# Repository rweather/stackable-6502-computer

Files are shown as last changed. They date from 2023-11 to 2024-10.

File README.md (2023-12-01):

Stackable 6502 Computer
=======================

This repository contains schematics, PCB layouts, and other information
for a "stackable" design for a 6502-based computer based on
[Ben Eater's Breadboard 6502 Computer](https://eater.net/6502) with
options to expand with daughter boards (or "shields" in the Arduino sense).

The CPU, memory, VIA, and address decoding are on the base board with pin
headers to connect to other boards:

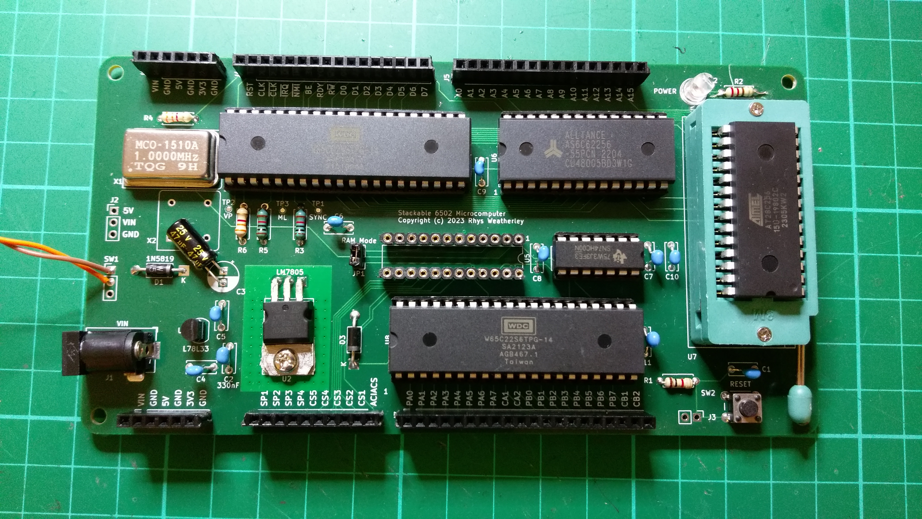
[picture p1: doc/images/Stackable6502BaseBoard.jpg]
Stackable 6502 Computer Base Board


Here is the Stackable 6502 Computer with the I/O board fitted:

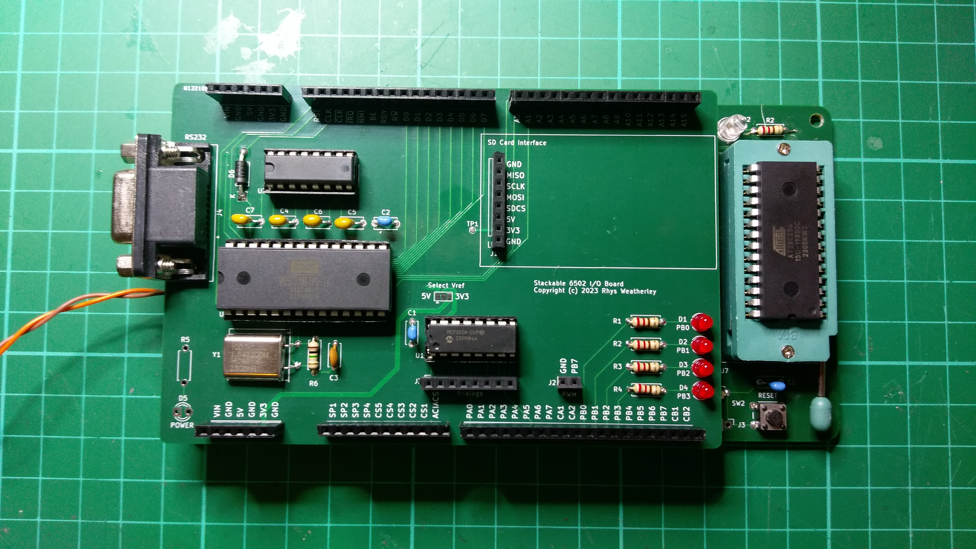
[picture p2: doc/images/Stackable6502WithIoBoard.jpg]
Stackable 6502 Computer with I/O Board


Other boards are possible in the future; see **Future Expansion Ideas** below.

Repository Layout
-----------------

* `kicad` - Schematics and PCB layouts in [KiCad format](https://www.kicad.org/).
* `kicad/BaseBoard` - Base board schematic and layout (4-layer).
* `kicad/IoBoard` - I/O board schematic and layout (2-layer).
* `kicad/Library` - Library of common schematic symbols and footprints.
* `schematics` - PDF versions of the schematics.
* `gerber` - Gerber files for all of the boards.
* `roms` - ROM images for test programs.
* `src` - Source code for test programs.

Schematics and Parts
--------------------

PDF versions of the schematics are available for the
[Base Board](schematics/BaseBoard.pdf) and [I/O Board](schematics/IoBoard.pdf)
in the `schematics` subdirectory.  The `gerber` directory contains the
Gerber files if you want to get your own PCB's made.

I used [PCBway](https://www.pcbway.com/) for my PCB's.  The PCB's for
the base board and I/O board are 4-layer boards.  You can order your
own PCB's from PCBway here:

* [Base Board](https://www.pcbway.com/project/shareproject/W132188ASZ13_Stackable_6502_BaseBoard_01ef6257.html)
* [I/O Board](https://www.pcbway.com/project/shareproject/W132188ASZ14_Stackable_6502_IoBoard_ac81ba96.html)

The parts list for this project can be found in the file
[Parts.md](doc/Parts.md) in the `doc` subdirectory.  There are some
alternatives on how you can build it, so some parts are optional:

* The 1MHz crystal oscillator can use either the 14-pin DIP style package (X1)
or the 8-pin DIP style package (X2) version.  Fit only one of the oscillators.
* Address decoding can use either a simple 74LS00 NAND gate, or a
ATF22V10C-7PX Programmable Logic Device (PLD).  It is easiest to start with
the NAND gate, but the PLD provides a lot of flexibility in memory layout.
* Optional 3.3V power supply using a L78L33 3.3V voltage regulator.
This will be handy if you plan to interface to 3.3V equipment using
level conversion.
* MCP3208 12-bit SPI ADC on the I/O board for reading analog inputs.

I suggest studying the schematics and the build instructions before
deciding which options you need.

Base Board
----------

The 156mm x 82mm base board was based on the design for
[Ben Eater's Breadboard 6502 Computer](https://eater.net/6502) with some
modifications to help with expandability:

* W65C02S or pin-compatible microprocessor.
* 62256 32K x 8 static RAM.
* 28C256 32K x 8 EEPROM, mounted in a 28-pin ZIF socket at the end of the
  base board to give clearance between the socket and daughter boards.
  A regular 28-pin socket can be used instead of the ZIF if you prefer.
* 6522 Versatile Interface Adapter (VIA).
* Address decoding logic using either a 74LS00 quad NAND gate as in Ben Eater's
  original design, or a ATF22V10C-7PX programmable logic device (PLD).
* 5V and 3.3V power supplies based on a 9-12V DC input.
* Pin headers to expose power, bus lines, and control lines to the
  attached daughter boards.
* 4-layer PCB with ground and 5V on the two inner layers.

The pin headers are aligned on a strict 2.54mm (0.1 inch) grid to allow
standard 120mm x 80mm stripboard or protoboard to be used when creating
daughter board "shields".

If you want to lay out your own shield PCB, then you can use the
`Stackable6502Shield` symbol and footprint from `kicad/Library`
as a starting point.

See [Build-Base-Board.md](doc/Build-Base-Board.md) in the `doc`
subdirectory for instructions on building the base board.

I/O Board
---------

The 125 x 82mm I/O board provides the following features:

* RS-232 serial interface using the 6551 ACIA, with RTS handshaking.
* SPI bus interface, connected to the 6522 VIA on the base board.
* SD card interface, connected to the SPI bus interface.
* 8 analog inputs using the MCP3208 12-bit SPI ADC chip.
* "PWM" header for square wave output on PB7 of the 6522 VIA.
  A piezo-buzzer can be connected to the header for making simple sounds.
* Provision for 3mm LED's on PB0..PB3 for indication.

As can be seen, the I/O board is very featureful.  Not all features need
to be fitted at once.  You can customise it for your requirements.

See [Build-Io-Board.md](doc/Build-Io-Board.md) in the `doc`
subdirectory for instructions on building the I/O board.

Future Expansion Ideas
----------------------

I'd like to design a memory expansion board with large amounts of
bank-switched RAM.  The ATF22V10C-7PX PLD can help with this, redirecting
memory requests away from the standard RAM to the additional banks.

SPI-based NAND or NOR flash chip for long term storage.  The contents of
flash could be loaded into the bank-switched RAM at startup to provide
ROM replacement capabilities.

An interface to an SPI-based Arduino LCD or OLED module may be interesting.

An alternative serial interface using a FTDI chip for serial over USB.

Address Decoding
----------------

The 74LS00 quad NAND gate on the base board implements the same memory
map as Ben Eater's original design:

* `0x0000 - 0x3FFF` - 16K of static RAM
* `0x4000 - 0x4FFF` - Unused
* `0x5000 - 0x5FFF` - ACIA
* `0x6000 - 0x6FFF` - VIA
* `0x7000 - 0x7FFF` - Do not use due to conflicts between the ACIA and VIA
* `0x8000 - 0xFFFF` - 32K of EEPROM

This arrangement is very wasteful of address space, particularly the
static RAM, but is very simple.  More complex arrangements require more
logic gates.

The ATF22V10C-7PX PLD provides greater flexibility in allocating address
ranges.  The PLD can be programmed to allocate the memory map in almost
any way, and to provide additional chip select outputs for devices on
daughter boards.  Addresses can be mapped with 64-byte granularity.

Note: I am still working on the PLD code.  More later.

License
-------

<p xmlns:cc="http://creativecommons.org/ns#" xmlns:dct="http://purl.org/dc/terms/"><span property="dct:title">Stackable 6502 Computer</span> by <span property="cc:attributionName">Rhys Weatherley</span> is licensed under <a href="http://creativecommons.org/licenses/by-nc-sa/4.0/?ref=chooser-v1" target="_blank" rel="license noopener noreferrer" style="display:inline-block;">Attribution-NonCommercial-ShareAlike 4.0 International</a></p>

Contact
-------

For more information on this project, to report bugs, or to suggest
improvements, please contact the author Rhys Weatherley via
[email](mailto:rhys.weatherley@gmail.com).

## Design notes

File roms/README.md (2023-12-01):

Self-Test
---------

The 32K `selftest.bin` ROM image is intended for boards that are
fitted with a 74LS00 for address decoding, just like the original
[Breadboard 6502 Computer](https://eater.net/6502) from Ben Eater.

The ROM performs a number of tests on the RAM, ROM, and peripherals
to verify correct operation.  It is assumed that four LED's have
been connected to PB0, PB1, PB2, and PB3 on the 65C22 VIA at
address 0x6000 in the memory map.

The tests begin by blinking all four LED's together three times.
Then it runs each of the tests, displaying the test number on the
LED's as it goes:

1. Test that the stack between `$0100` and `$01FF` appears to work.
2. Test that the zero page between `$0000` and `$00FF` appears to work.
3. Write test values to all of RAM (except the stack and zero page).
4. Read the test values back from RAM and verify them.
5. Test that the BRK instruction will generate a BREAK interrupt.
6. Test that timer interrupts can be generated from the 65C22 VIA.
7. Beep the piezobuzzer on PB7 for 100ms with a 1kHz square wave.
8. Test that code can be executed from all addresses in ROM.

If a test fails, the number of the test that failed is displayed on the
LED's and testing stops.  If all tests pass, then a Knight Rider style
LED chase will be done to indicate success.

If you have a 65C51 ACIA connected at address 0x5000 in the memory map,
then you can connect a serial terminal program at 19200 N-8-1 to
see additional messages.  If you see messages like "Self test started!"
and "Stack check: Running", then you know that serial transmit on
the ACIA is working.

At the end of the tests, you can type characters at the serial terminal
and they should be echo'ed back to you.  This tells you that serial
receive on the ACIA is working.

There are many things that are not yet tested, but the above tests
should give a pretty good indication if the board is wired up properly.

The source code for the self test is under `src/selftest` in the
repository.

Music Examples
--------------

The ROM images `happy_birthday.bin` and `merry_christmas.bin` play
music on a piezobuzzer between PB7 and ground.  This uses the
square wave output feature on the 65C22 VIA.

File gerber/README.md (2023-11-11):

Note that BaseBoard and IoBoard both use 4 layers.  You need to mention
that explicitly to your PCB supplier; e.g. PCBway.

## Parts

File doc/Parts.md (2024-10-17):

Parts List for the Stackable 6502 Computer
==========================================

There is no kit that you can buy yet for this design, but if you have
already built or plan to build [Ben Eater's Breadboard 6502 Computer](https://eater.net/6502), then most of the components can be gotten from his kits.
Build the breadboard version first, following his
[instructions on YouTube](https://www.youtube.com/playlist?list=PLowKtXNTBypFbtuVMUVXNR0z1mu7dp7eH).
Then solder up a permanent one using the same parts plus a few extras!

You will need at least the basic "6502 Computer Kit", the
"6502 Serial Interface Kit", and of course an "EEPROM Programmer".
I have marked the parts that you can get from Ben's kits with (BE) below.

Base Board
----------

* PCB; see the `gerber/BaseBoard` directory for the 4-layer Gerbers,
or [purchase it from PCBway](https://www.pcbway.com/project/shareproject/W132188ASZ13_Stackable_6502_BaseBoard_01ef6257.html).
* Integrated Circuits:
  * 1 x W65C02SxP microprocessor, 40-pin DIP (BE)
  * 1 x W65C22NxP Versatile Interface Adapter, 40-pin DIP (VIA) (BE)
  * 1 x 62256 32 kByte static RAM, 28-pin DIP (BE)
  * 1 x 28C256 32 kByte EEPROM, 28-pin DIP (BE)
  * 1 x 74LS00 or 74HC00 NAND gate (not needed if using the ATF22V10C-7PX), 14-pin DIP (BE)
  * 1 x ATF22V10C-7PX Programmable Logic Device, 24-pin DIP (optional)
  * 1 x LM7805 5V voltage regulator (TO-220 package)
  * 1 x L78L33 3.3V voltage regulator (TO-92 package) (optional, 3.3V supply only)
* IC Sockets:
  * 2 x 40-pin wide DIP sockets (15.24mm width) (for W65C02SxP and W65C22NxP)
  * 1 x 14-pin narrow DIP socket (7.62mm width) (for 74LS00)
  * 1 x 28-pin wide DIP socket (15.24mm width) (for 62256)
  * 1 x 24-pin narrow DIP socket (7.62mm width) (for ATF22V10C-7PX)
  * 1 x 28-pin ZIF socket (for 28C256, or use an ordinary 28-pin wide DIP socket instead)
* Resistors:
  * 1 x 220R resistor (BE)
  * 1 x 1K resistor (BE)
  * 2 x 3.3K resistor
  * 2 x 10K resistor
* Capacitors:
  * 9 x 100nF ceramic or monolithic capacitor (BE)
  * 1 x 330nF ceramic or monolithic capacitor (220nF is sufficient in a pinch)
  * 1 x 47uF electrolytic capacitor, 16V rating or better
* Diodes and LED's:
  * 2 x Schottky diodes, 1N5189, SB140, or equivalent
  * 1 x 5mm LED for power indication (red, green, blue, etc - your choice) (BE)
* Stackable pin headers, 2.54mm pitch:
  * 2 x 6-pin
  * 1 x 10-pin
  * 1 x 20-pin
  * 2 x 16-pin
* Other:
  * 1 x 1MHz crystal oscillator module in either 14-pin or 8-pin DIP package (BE)
  * 1 x pushbutton switch for RESET
  * 1 x SPDT slider switch for power (can be mounted off-board)
  * 1 x DC barrel jack
  * 1 x 2-pin 2.54mm header plus jumper if using the 74LS00 and JP1
  * 1 x 9V or 12V DC plug pack / wall wart

I/O Board
---------

* PCB; see the `gerber/IoBoard` directory for the 4-layer Gerbers, or
[purchase it from PCBway](https://www.pcbway.com/project/shareproject/W132188ASZ14_Stackable_6502_IoBoard_ac81ba96.html).
* Integrated Circuits:
  * W65C51NxP Asynchronous Communications Interface Adapter (ACIA), 28-pin DIP (BE)
  * MAX232 RS-232 line driver, 16-pin DIP (BE)
  * MCP3208 12-bit SPI ADC, 16-pin DIP (optional, only needed if you need analog inputs)
* IC Sockets:
  * 1 x 28-pin wide DIP socket (15.24mm width) (for W65C51NxP)
  * 2 x 16-pin narrow DIP sockets (7.62mm width) (for MAX232 and MCP3208)
* Resistors:
  * 5 x 220R resistor (BE)
  * 1 x 1M resistor
* Capacitors:
  * 2 x 100nF ceramic or monolithic capacitor (BE)
  * 1 x 22pF ceramic capacitor (20pF or 30pF will also work) (BE)
  * 4 x 1uF ceramic or non-polarized capacitor (BE)
* Diodes and LED's:
  * 1 x Schottky diode, 1N5189, SB140, or equivalent
  * 5 x 3mm red or green LED's for power indication and digital outputs (5mm will also work - BE)
* Stackable pin headers, 2.54mm pitch:
  * 2 x 6-pin
  * 1 x 10-pin
  * 1 x 20-pin
  * 2 x 16-pin
* Other:
  * 1 x 1.8432MHz crystal oscillator module in HC49 package (BE)
  * 1 x DB9 female right angle connector
  * 2 x 2.54mm low height 8-pin headers for the SD card interface and analogs
  * 1 x 2.54mm low height 2-pin header for the PWM connector

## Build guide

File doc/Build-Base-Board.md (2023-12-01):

Building the Base Board of the Stackable 6502 Computer
======================================================

See the [Parts.md](Parts.md) file for a list of parts.  It is assumed that
you are familiar with soldering through hole parts.  There are no surface
mount parts in the Base Board.  Sockets are recommended for the chips
as there will be a lot of handling while soldering up all the components.

Some of the components are marked on the schematic; e.g. U1 is L78L33,
but others aren't marked.  I got lazier the longer I worked on the PCB layout.
Sorry.

The PDF of the Base Board schematic can be found [here](../schematics/BaseBoard.pdf).

The following 3D rendering from KiCad shows the location of the major
components:

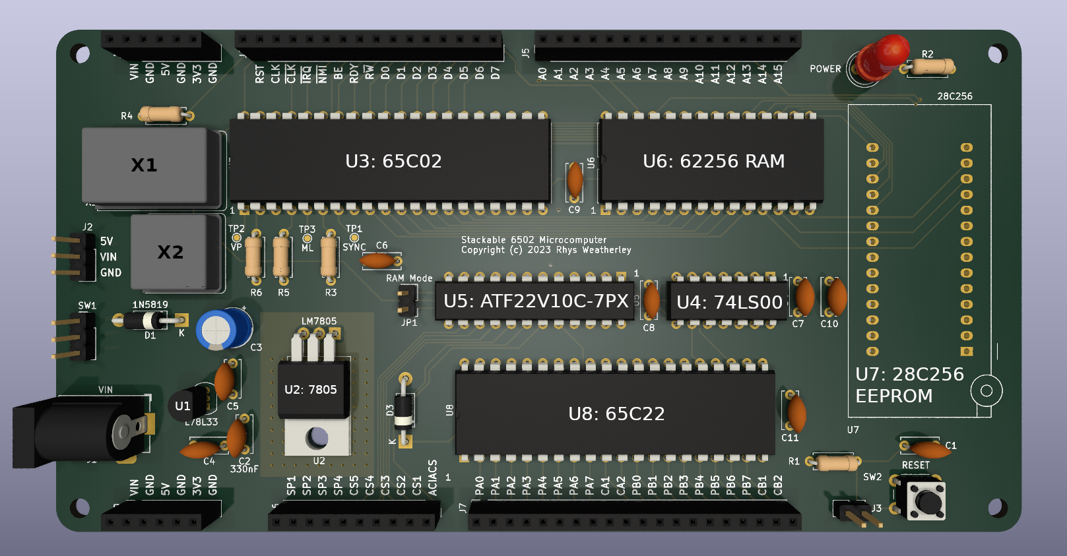
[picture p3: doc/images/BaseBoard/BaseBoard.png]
Base board layout


Here are all of the steps if you want to skip ahead:

* [Step 1: Resistors](#step-1)
* [Step 2: Diodes](#step-2)
* [Step 3: IC Sockets](#step-3)
* [Step 4: Crystal Oscillator](#step-4)
* [Step 5: Ceramic Capacitors](#step-5)
* [Step 6: Power Supply](#step-6)
* [Step 7: Smoke Test!](#step-7)
* [Step 8: EEPROM Socket](#step-8)
* [Step 9: Fit the chips](#step-9)
* [Step 10: Fit the pin headers](#step-10)
* [Step 11: Testing and troubleshooting](#step-11)

<a name="step-1"/>

## Step 1: Resistors

As with all through hole projects, start with the low profile resistors:

* R1 - 1K
* R2 - 220R (see the note below)
* R3 - 10K
* R4 - 3.3K
* R5 - 10K
* R6 - 3.3K

R2 is the current-limiting resistor for the power LED (D2).  The value of
this resistor will depend upon the current rating of your LED.  220R is
suitable for simple red/green LED's rated for 15mA to 20mA.  Increase the
resistance for LED's with lower current ratings.

1K should be safe for most LED types but it may be dim.  I actually started
with 1K but my LED was too dim so I changed it to 220R later in the build.

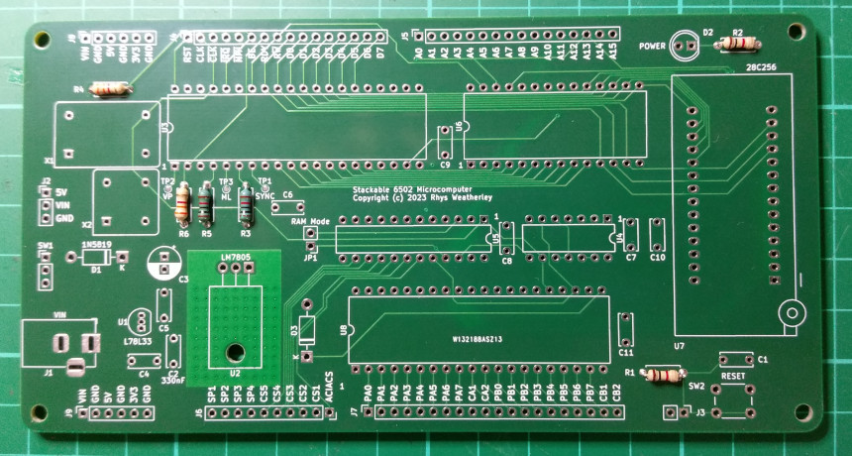
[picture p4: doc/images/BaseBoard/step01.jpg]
Resistors fitted


<a name="step-2"/>

## Step 2: Diodes

Fit the two Schottky diodes (D1 and D3).  Almost any Schottky should do:
1N5819 or SB140 or equivalent.  Make sure the diodes are oriented the
right way around.

D1 should be rated for 1A or more as it delivers power to the entire base
board and any daughter boards.  The LM7805 voltage regulator U2 is also
rated for 1A, so you can't go over 1A unless you replace both D1 and U2
with higher-spec'ed components.

Another option for high power operation is to bypass the on-board power
supply entirely and feed 5V in via J2 from an external power supply.

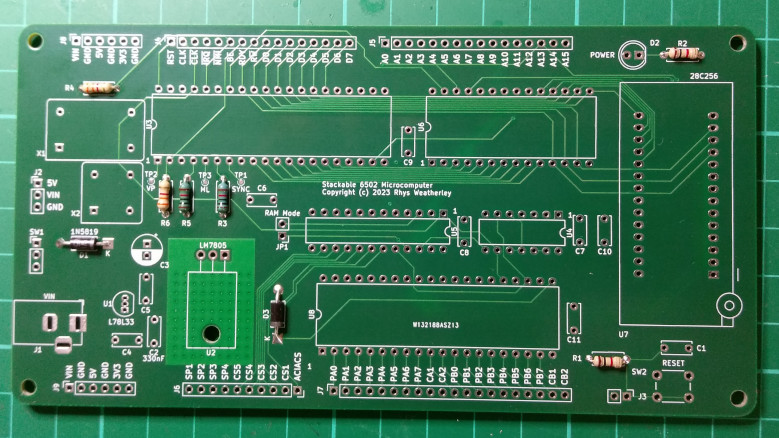
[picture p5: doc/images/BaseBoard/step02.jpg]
Diodes fitted


<a name="step-3"/>

## Step 3: IC Sockets

Next it is time for the IC sockets:

* U3 - 40-pin DIP socket - 65C02 microprocessor.
* U4 - 14-pin DIP socket - 74LS00 NAND gate.
* U5 - 24-pin DIP socket - ATF22V10C-7PX Programmable Logic Device (optional).
* U6 - 28-pin DIP socket - 62256 32K static RAM.
* U8 - 40-pin DIP socket - 65C22 Versatile Interface Adapter (VIA).

In this step I have not yet fitted the socket for U7 (28C256 EEPROM) as I
will be fitting a 28-pin ZIF socket later.  But if you don't want to use a
ZIF socket, then you can fit a plain 28-pin socket for U7 in this step.

If you prefer to solder your chips down without IC sockets, then you should
still use sockets for U5 and U7.  Otherwise you won't be able to remove the
ATF22V10C-7PX PLD and 28C256 EEPROM from the board to reprogram them later!

<b>Note:</b> U4 and U5 are oriented with the notch and pin 1 facing right
instead of the usual left for all other chips.  This made it easier to route
the PCB.  Make sure you orient the sockets correctly to remind you which
direction to insert the chips later.

I like to hold the sockets in position with masking tape while soldering
the first few pins:

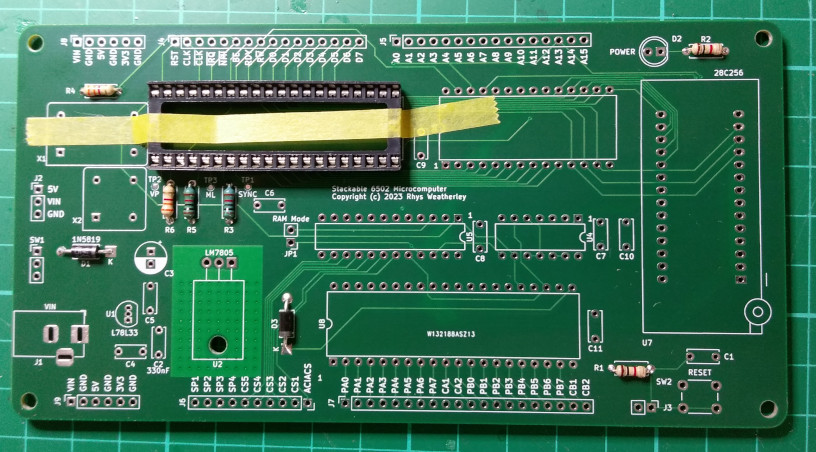
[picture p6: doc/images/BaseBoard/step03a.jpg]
IC sockets with tape


Afterwards, the board should look like the picture below.  This configuration
is for when using the 74LS00 NAND gate for address decoding (U5 not fitted).

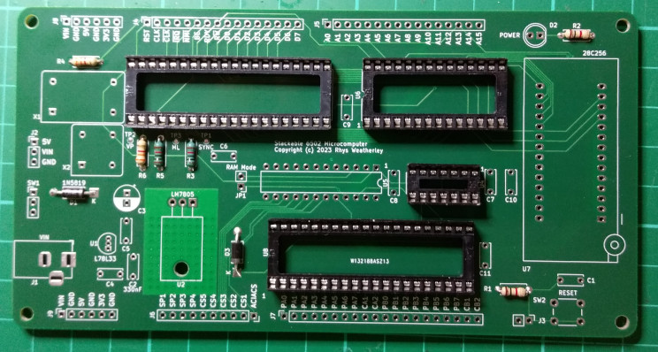
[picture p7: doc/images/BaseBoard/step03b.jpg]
IC sockets fitted


<a name="step-4"/>

## Step 4: Crystal Oscillator

Next fit the 1MHz crystal oscillator module.  The PCB has provision for
either the 14-pin DIP sized package (X1) or the 8-pin DIP sized package (X2).
I had the 14-pin variety, but fit the other one if you have that.
Only fit one.

I soldered the oscillator directly to the board, with no socket.  There are
only 4 pins so it isn't difficult to desolder later if necessary.  Make sure
that pin 1 is on the lower left.

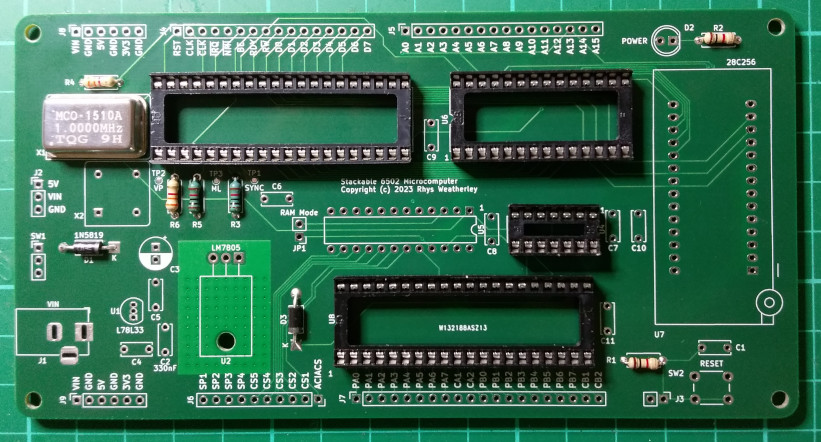
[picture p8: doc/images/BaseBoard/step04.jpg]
Crystal oscillator fitted


<a name="step-5"/>

## Step 5: Ceramic Capacitors

Next up are the ceramic capacitors.  Most of them are 100nF.  Monolithic
capacitors are also fine.

* C1, C4-C11 - 100nF
* C2 - 220nF or 330nF - the datasheet for the L78L33 voltage regulator
recommends 330nF, but 220nF is also ok because C2 is in parallel with the
100nF C5: 220nF + 100uF = 320nF which is close enough.

I also fitted the reset pushbutton SW2 in this picture.  If you want a
panel-mounted reset pushbutton, you can wire it up to J3 next to SW2.

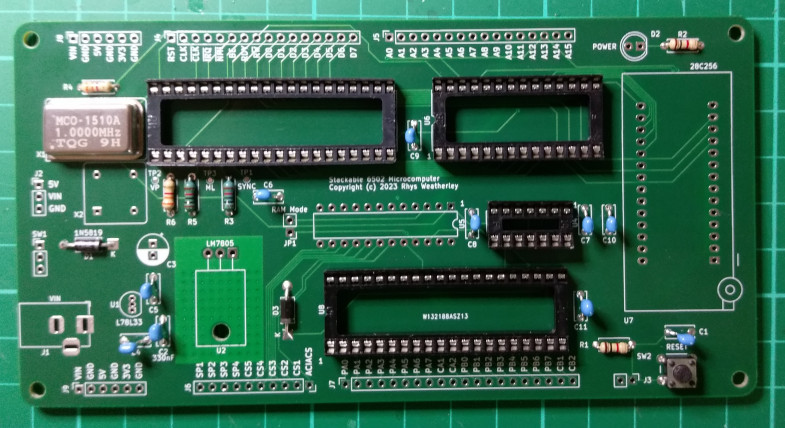
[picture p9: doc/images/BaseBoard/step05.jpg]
Ceramic apacitors fitted


<a name="step-6"/>

## Step 6: Power Supply

The remaining components relate to the power supply for the board:

* C3 - 47uF electrolytic capacitor, 16V or better rating.
* U1 - L78L33 3.3V voltage regulator, TO-92 package.
* U2 - LM7805 5V voltage regulator, TO-220 package.
* D2 - 5mm power LED - red, green, white, blue, ... - your choice!  I chose blue.
* J1 - DC barrel jack, positive on the center pin.

These components must be oriented properly, so check the markings carefully.
I laid the 47uF capacitor on its side to clear the upper I/O board / shield.

I put a piece of thermal tape under the LM7805 to thermally bond it to
the board.  Make sure you bolt the voltage regulator down before you
solder the 3 pins.  Otherwise you might stress the package when bolting later.

The pins on the L78L33 are very close together, so you will need a fine
soldering tip.  If you mess up and bridge the pins (like I did!),
run the iron between the pins to melt the solder and create a gap.
Check the result carefully with a magnifier and multimeter to ensure
you don't have a dead short from 5V or 3.3V to ground.

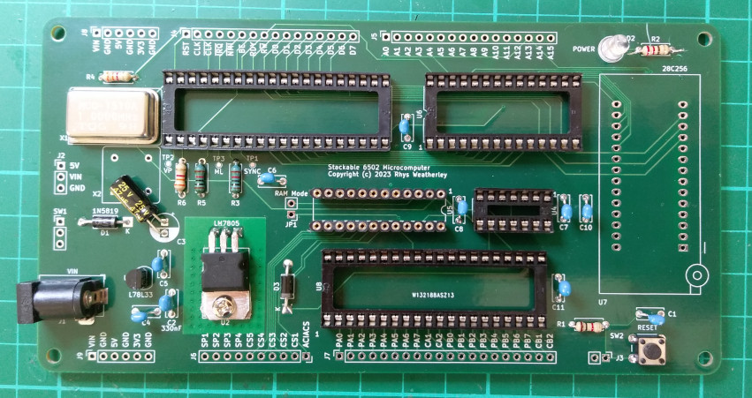
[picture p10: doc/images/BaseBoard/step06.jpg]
Power supply fitted


You can also see that I fitted some breakaway IC socket pins for U5 because
I didn't have a 24-pin DIP socket handy.

<a name="step-7"/>

## Step 7: Smoke Test!

Before fitting the ZIF socket or the chips, power the board on with a
9V to 12V DC plugpack (wall wart) and check that the blue smoke
doesn't escape!  If all goes well, the power LED should light up.

Check that the LM7805 and L78L33 voltage regulators don't get hot.
If they do feel hot, then there is probably a short from 5V or 3.3V to
ground somewhere.  Turn the board off and check the continuity of the
board with a multimeter.

To make testing easier, I connected a slider switch up to the SW1 pins.
Eventually I plan to have a panel-mounted switch on the enclosure.

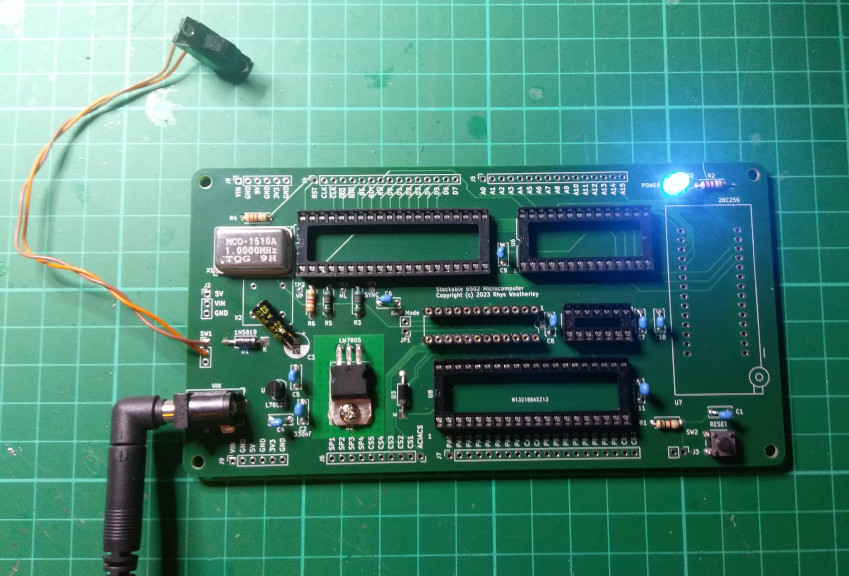
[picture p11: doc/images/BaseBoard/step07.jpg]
Smoke test


Turn the board off and then go around all pins on the chips to check
that they are connected up properly according to the schematic using a
multimeter in continuity mode.  Make sure there aren't any shorts between
the data and address lines in particular.

<a name="step-8"/>

## Step 8: EEPROM Socket

Now we can fit the 28-pin ZIF socket for the 28C256 EEPROM:

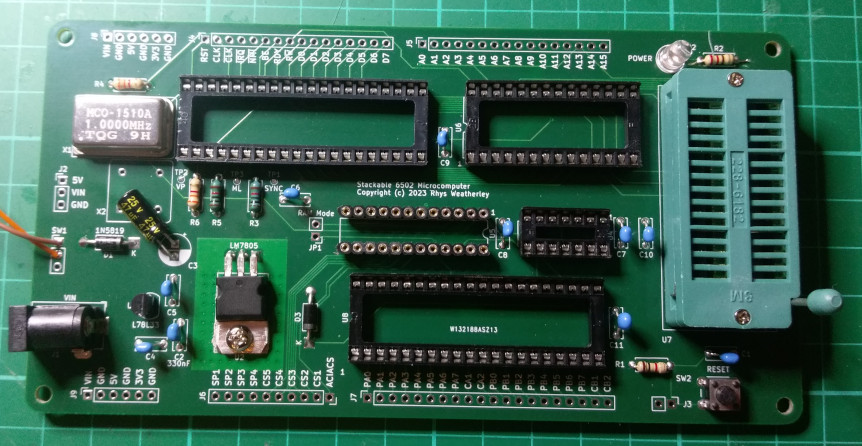
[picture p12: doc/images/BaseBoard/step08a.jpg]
EEPROM ZIF socket fitted


If you prefer, you can use a regular 28-pin DIP socket instead (I didn't
actually solder this - I just put it in place to show where it would go):

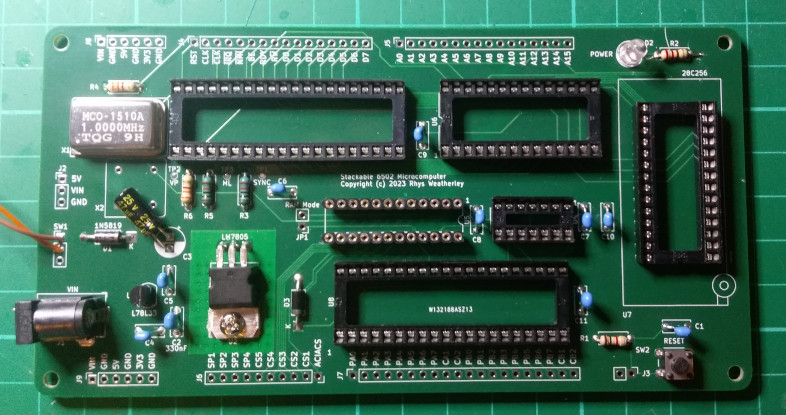
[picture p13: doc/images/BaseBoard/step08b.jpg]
EEPROM DIP socket fitted


<a name="step-9"/>

## Step 9: Fit the chips

It is now time to fit the chips.  One thing I forgot was the "RAM Mode"
jumper JP1 next to U5.  It must be fitted if you are using the 74LS00
NAND gate for address decoding.  This is what the board should look
like when using the 74LS00:

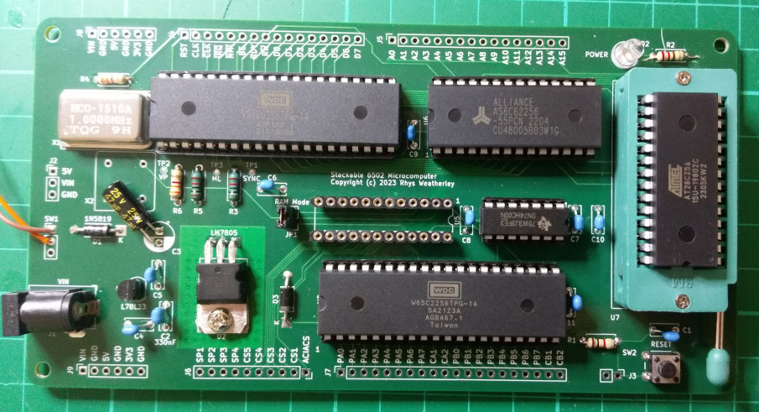
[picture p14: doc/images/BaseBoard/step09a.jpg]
All chips fitted


And this is what the board should look like when using the ATF22V10C-7PX
programmable logic device (PLD).  Note that the jumper on "RAM Mode" / JP1
is not fitted when using the PLD:

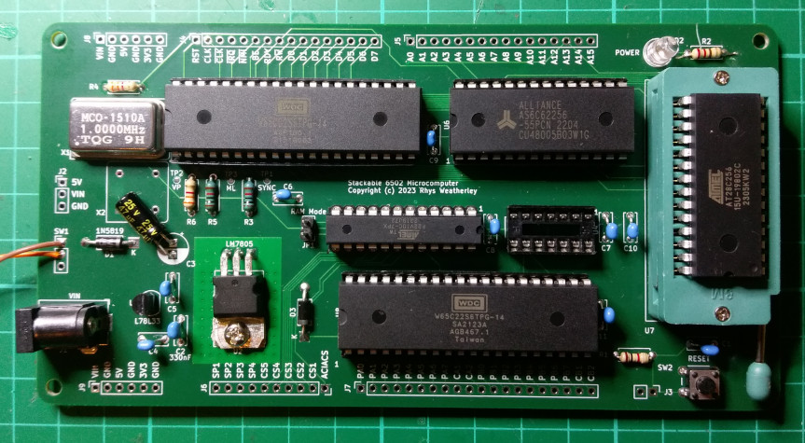
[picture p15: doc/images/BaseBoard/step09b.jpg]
All chips fitted alternate


Check that the chips are oriented correctly and that there are no bent pins.
Then check the continuity of the board again to make sure that the right pins
are connected to each other.

You can do a second smoke test at this point to make sure there are
no shorts due to the chips.  The 5V and 3.3V voltage regulators should
remain cool when the power is applied.  If they get really hot, then turn
everything off and check for shorts or chips that are in backwards.

<a name="step-10"/>

## Step 10: Fit the pin headers

Next fit the 2.54pm pin headers, such as
[these ones from Adafruit](https://www.adafruit.com/product/598).
Cut the six required headers to size:

* 2 x 6 pin headers for the voltage rails.
* 2 x 16 pin headers for address, data, and control lines.
* 1 x 10 pin header for the chip selects and spare pins.
* 1 x 20 pin header for the I/O ports on the 65C22 VIA.

When cutting the headers, score the cutting point with a hobby knife and
then snap the headers off with a pair of pliers.  The pin inserts tend to fall
out if you cut too close to the pins you want to keep.  I usually score the
cutting point close to the next pin.  You will lose one pin insert,
but you will have all the required pins in the snapped off portion.

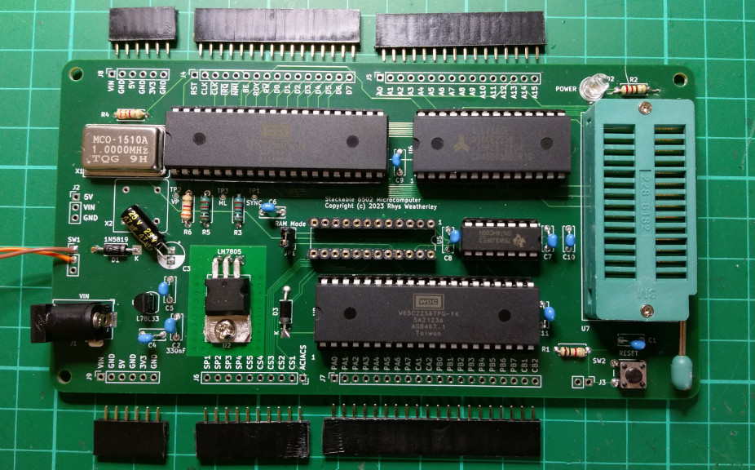
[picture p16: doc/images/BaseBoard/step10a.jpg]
Stackable headers cut


Lining up the headers for hand soldering can seem like a challenge, but it is
quite easy when you know how.  Cut the stackable headers for the I/O board,
and then threaded them through into the base board's pin headers using a
piece of protoboard:

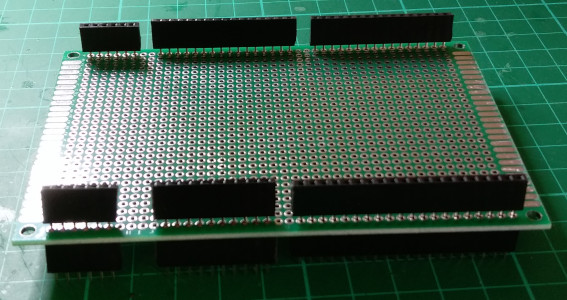
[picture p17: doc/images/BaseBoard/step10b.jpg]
Protoboard header alignment


Veroboard will also work.  Or you could use the bare PCB for the I/O board
without any components on it.  You can now insert the headers into the
base board and turn the whole contraption upside down:

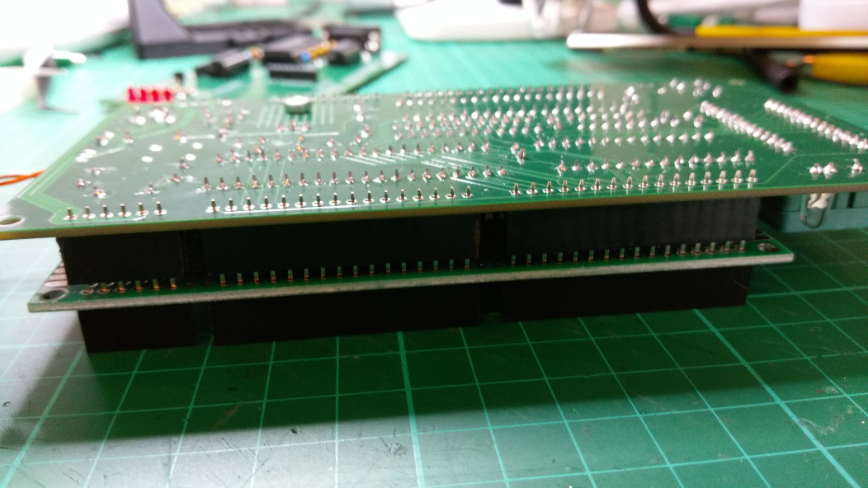
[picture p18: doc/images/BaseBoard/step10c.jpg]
Protoboard and base board


The contraption may be a little wobbly side to side because there is no
solder holding the pins rigidly in place yet.  It can be useful to clamp
the contraption between two books with flat spines.  I used some manuals
for a pair of ancient computer languages:

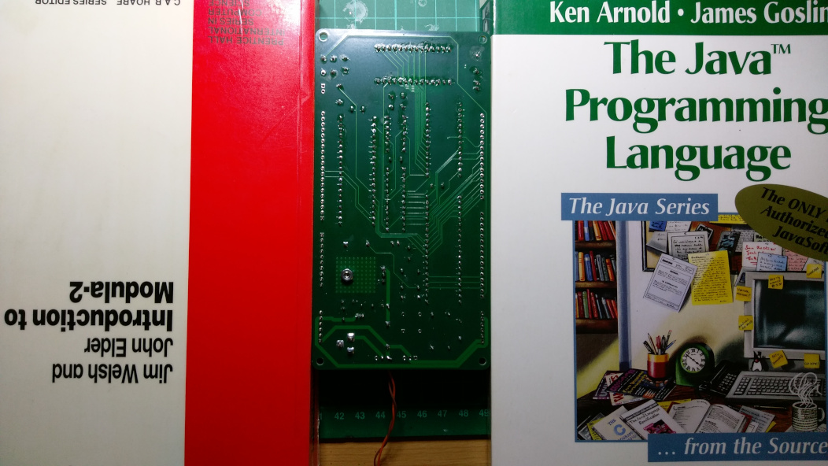
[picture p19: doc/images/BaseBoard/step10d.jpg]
Protoboard and base board, clamped


Check underneath that the pin headers are vertical and then solder 2 pins
on the ends of each header.  This will make the contraption more rigid.
You can then remove the books and solder the rest of the pins.

And here it is, all done!

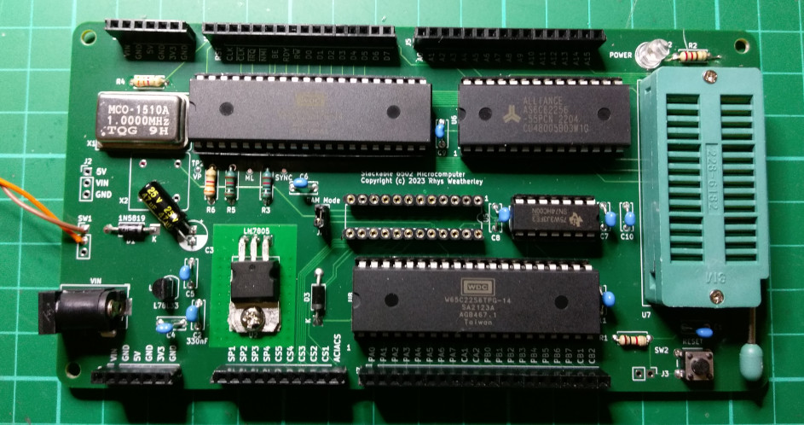
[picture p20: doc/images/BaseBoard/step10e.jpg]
Base board fully soldered


Now that the soldering of the base board is complete, you may want to give
the underside a good cleaning with isopropyl alcohol to remove the excess flux.

<a name="step-11"/>

## Step 11: Testing and Troubleshooting

The `roms` subdirectory in the repository contains a file called
`selftest.bin`.  Program this into an AT28C256 EEPROM and insert it
into the ROM socket (U7).  The source code is under `src/selftest`.

Connect the anodes of four LED's to PB0, PB1, PB2, and PB3.  Connect the
cathodes of the LED's through 220R or 1K resistors to ground.  If you have a
piezobuzzer, then connect it between PB7 and ground.  My setup is
shown in this picture (ignore the pushbutton and the 555 timer - they are a
permanent fixture on my breadboard):

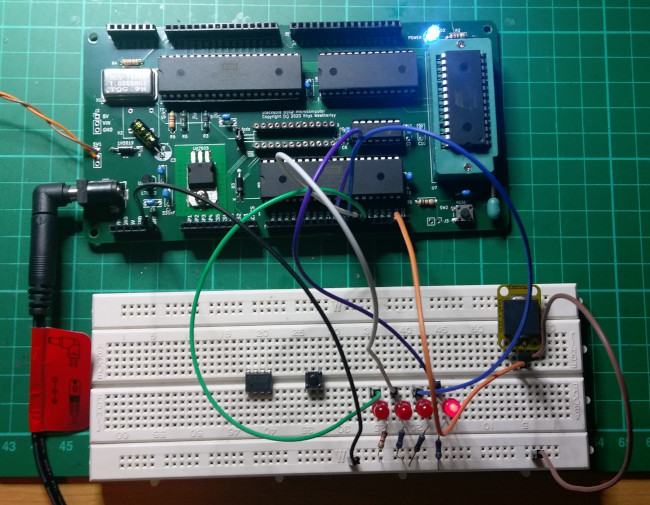
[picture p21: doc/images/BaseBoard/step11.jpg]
Base board with breadboard


Power on the board.  Check that the LM7805 and L78L33 voltage regulators
aren't getting hot.  If they are, then there may be a short between
power and ground on the board - turn the board off and look for the short.
As mentioned above, it can be very easy to bridge the pins on the
L78L33 so I recommend checking that first.

If you have a multimeter or a bench power supply that shows the
current draw, you can use it to measure the input current.  The current
should be around 20mA to 50mA when running the self-test.

The self-test ROM starts by blinking all LED's three times and then it
runs the tests.  As each test runs, the test number is shown on the LED's
in binary.  If all tests pass, the LED's will chase back and forth
Knight Rider style in celebration.  If a test fails, the LED's will get
stuck displaying the number of the test that failed.

Here are the tests that are run.  Each test takes about 1 second when
the CPU is clocked at 1MHz:

1. Test that the stack between `$0100` and `$01FF` appears to work.
2. Test that the zero page between `$0000` and `$00FF` appears to work.
3. Write test values to all of RAM (except the stack and zero page).
4. Read the test values back from RAM and verify them.
5. Test that the BRK instruction will generate a BREAK interrupt.
6. Test that timer interrupts can be generated from the 65C22 VIA.
7. Beep the piezobuzzer on PB7 for 100ms with a 1kHz square wave.
8. Test that code can be executed from all addresses in ROM.

If a test fails, then the most likely cause is that a chip is fitted
backwards or you have bent one of the pins trying to insert the chip
into its socket.  Also make sure that you have fitted the JP1 jumper
when using the 74LS00 NAND gate for address decoding.

If no LED's light up, then there may be something wrong with the clock
signal to the CPU.  Check it with an oscilloscope on the CLK header pin.
Or use a multimeter - the average voltage should hover about half-way
between 5V and ground.

If everything passes, then you have a working Stackable 6502 Base Board!
Congratulations!  Next is the [I/O Board](Build-Io-Board.md).

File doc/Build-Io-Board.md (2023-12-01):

Building the I/O Board of the Stackable 6502 Computer
=====================================================

See the [Parts.md](Parts.md) file for a list of parts.  It is assumed that
you are familiar with soldering through hole parts.  There are no surface
mount parts in the I/O Board.  Sockets are recommended for the chips
as there will be a lot of handling while soldering up all the components.

The PDF of the I/O Board schematic can be found [here](../schematics/IoBoard.pdf).

The following 3D rendering from KiCad shows the location of the major
components:

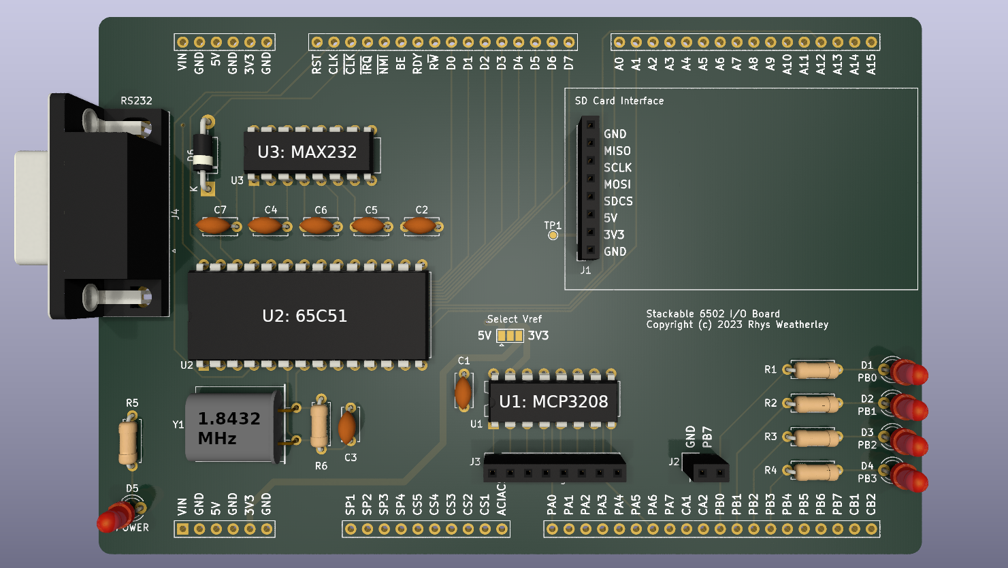
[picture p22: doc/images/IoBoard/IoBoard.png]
I/O board layout


Here are all of the steps if you want to skip ahead:

* [Step 1: Resistors and Diodes](#step-1)
* [Step 2: IC Sockets](#step-2)
* [Step 3: Capacitors](#step-3)
* [Step 4: Crystal](#step-4)
* [Step 5: Indicator LED's](#step-5)
* [Step 6: Connectors](#step-6)
* [Step 7: Fit the chips](#step-7)
* [Step 8: Extra modules](#step-8)
* [Step 9: Fit the stackable headers](#step-9)
* [Step 10: Testing and Troubleshooting](#step-10)

<a name="step-1"/>

## Step 1: Resistors and Diodes

As with all through hole projects, start with the low profile components:

* R1 to R5 - 220R (see the note below)
* R6 - 1M
* D6 - Schottky diode, 1N5819 or SB140 or equivalent.  Make sure the diode
is oriented the right way around.

R1 to R2 are current-limiting resistors for the indicator and power LED's
(D1 to D5).  The value of this resistor will depend upon the current rating of
your LED.  220R is suitable for simple red/green LED's rated for 15mA to 20mA.
Increase the resistance for LED's with lower current ratings.  1K should be
safe for most LED types but it may be dim.

I didn't fit R5 and D5 in my build because I already had a power LED on
the base board.  But you can add them if you want some visual indication
that the I/O board is getting power from the base board.

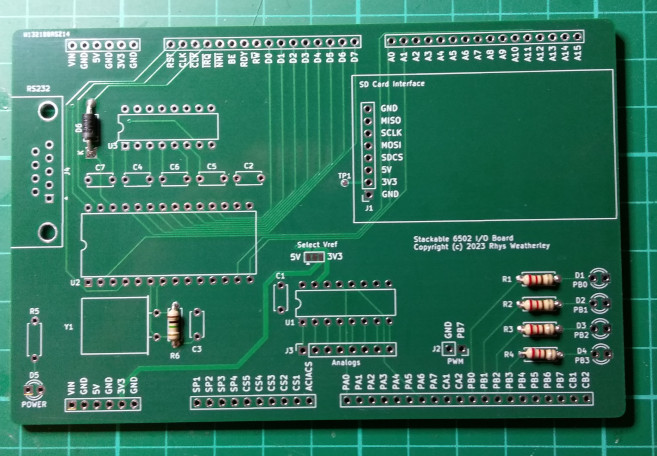
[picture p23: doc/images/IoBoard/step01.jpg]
Resistors and diodes fitted


<a name="step-2"/>

## Step 2: IC Sockets

Next it is time for the IC sockets:

* U1 - 16-pin DIP socket - MCP3208 12-bit SPI ADC (optional).
* U2 - 28-pin DIP socket - 65C51 ACIA.
* U3 - 16-pin DIP socket - MAX232 RS-232 line driver.

The pin 1 notch on all chips points towards the left of the PCB.

You can solder the chips directly to the board if you want, but IC sockets
makes it easier to replace them later if they fail or to remove them when
diagnosing faults.

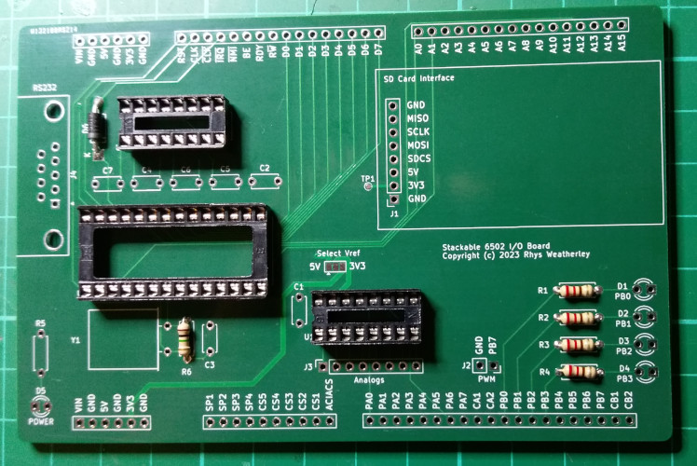
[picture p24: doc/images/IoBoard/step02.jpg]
IC sockets fitted


<a name="step-3"/>

## Step 3: Capacitors

Next up are the capacitors.

* C1, C2 - 100nF ceramic or monolithic capacitors.
* C3 - 22pF ceramic capacitor.  Can use 20pF or 30pF instead if you have
those instead.
* C4 - C7 - 1uF ceramic or monolithic capacitors.

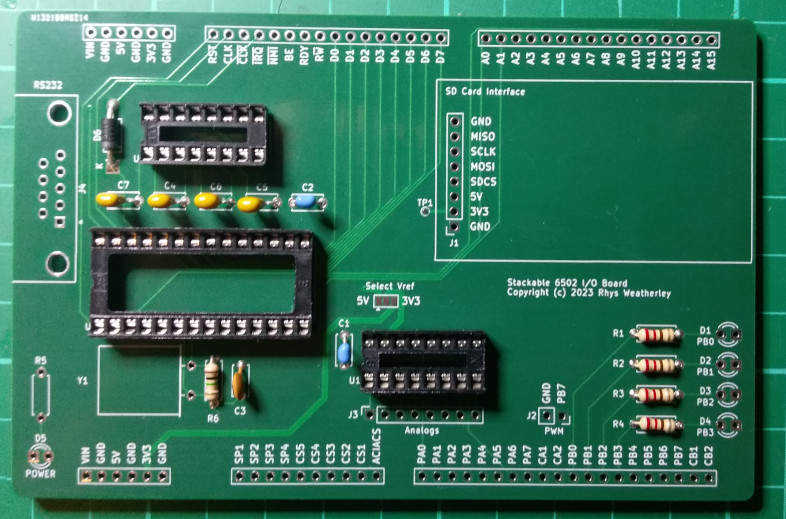
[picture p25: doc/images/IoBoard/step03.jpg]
Capacitors fitted


<a name="step-4"/>

## Step 4: Crystal

Next fit the 1.8432MHz crystal Y1, lying down flat on the PCB to reduce
vertical height:

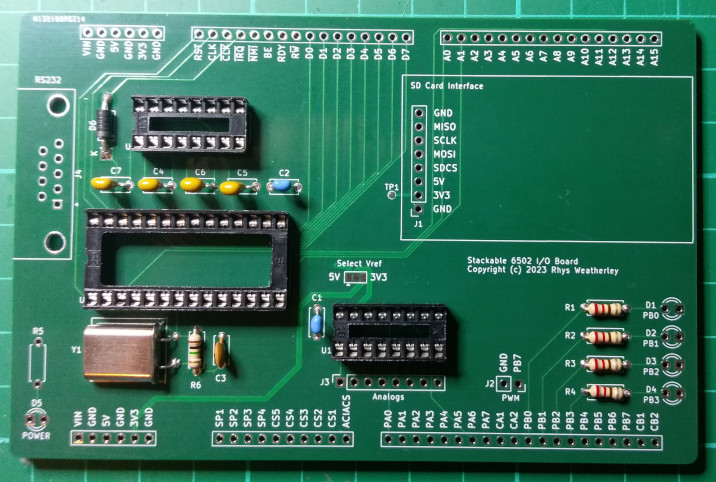
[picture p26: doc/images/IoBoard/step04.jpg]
Crystal fitted


<a name="step-5"/>

## Step 5: Indicator LED's

Now fit the four indicator LED's on PB0 to PB3.  Make sure you orient
them with the cathode (flat side) toward the edge of the PCB.

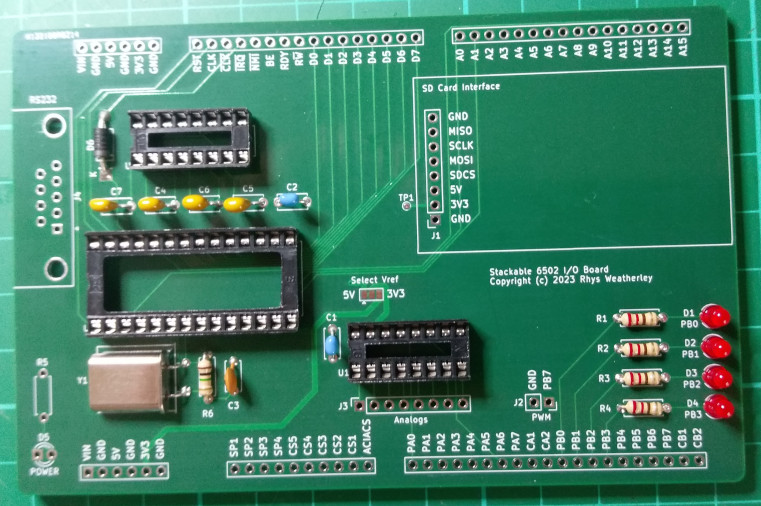
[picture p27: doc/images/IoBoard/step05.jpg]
LED's fitted


<a name="step-6"/>

## Step 6: Connectors

Fit half-height 2.54mm pin headers to J1, J2, and J3, such as
[these ones from Adafruit](https://www.adafruit.com/product/3008).
Then fit the female DB9 connector to J4.

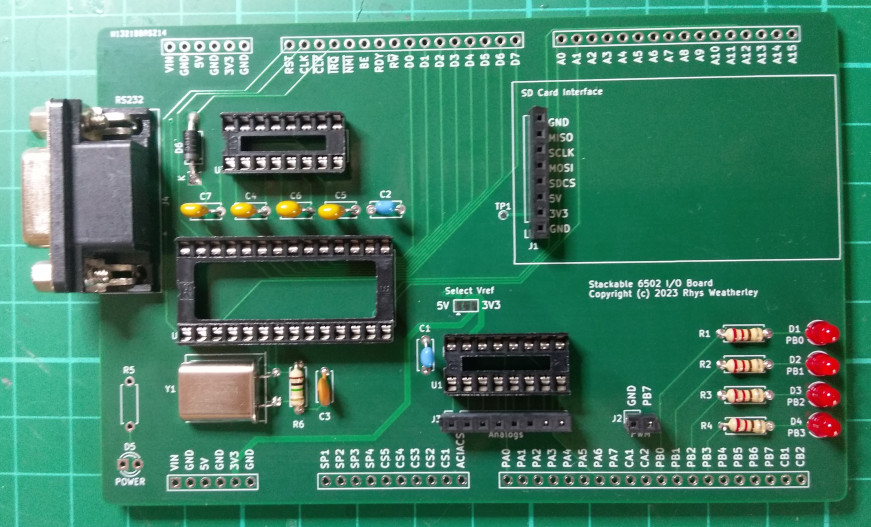
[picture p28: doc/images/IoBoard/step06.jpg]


<a name="step-7"/>

## Step 7: Fit the chips

It is now time to fit the chips.  Check that the chips are oriented correctly
with pin 1 towards the left side of the PCB, and that there are no bent pins.
Then check the continuity of the board against the schematic to make sure
that the right pins are connected to each other.

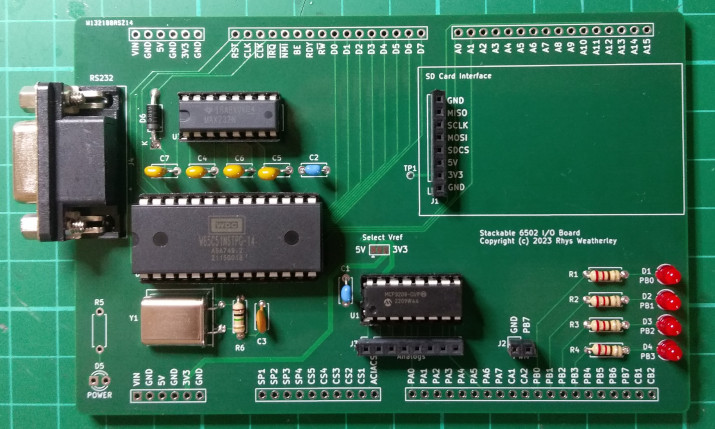
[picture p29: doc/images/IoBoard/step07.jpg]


<a name="step-8"/>

## Step 8: Extra modules

J1 was designed to take a [5V Arduino SD card module](https://www.jaycar.com.au/arduino-compatible-sd-card-interface-module/p/XC4386)
that I got from Jaycar in Australia.

There are other SD card modules from Adafruit, Sparkfun, and others.
But the pinouts aren't always the same.  You may have to make an adapter to
connect them to J1.  J1 has the following pin-out:

* 1 - Ground
* 2 - 3.3V supply from the voltage regulator on the SD card module itself
* 3 - 5V supply to the SD card module
* 4 - SD card chip select (PA5 on the 65C22 VIA)
* 5 - MOSI (PA1 on the 65C22 VIA)
* 6 - SPI clock (PA0 on the 65C22 VIA)
* 7 - MISO (PA6 on the 65C22 VIA)
* 8 - Ground

5V Arduino SD card modules tend to have an on-board 3.3V supply,
which is broken out as test point TP1 on the PCB.  This is not
connected to the 3.3V supply from the base board.  But if you
didn't fit the 3.3V supply on the base board, you could use the
3.3V supply from the SD card module instead.  Run a wire from
TP1 to the 3.3V line.

J2 makes Ground and PB7 available.  I usually plug in a piezobuzzer module
for making simple sounds using the square wave output capability of
the 65C22 Versatile Interface Adaptor (VIA) on the base board.

You can see the two modules that I used in this picture:

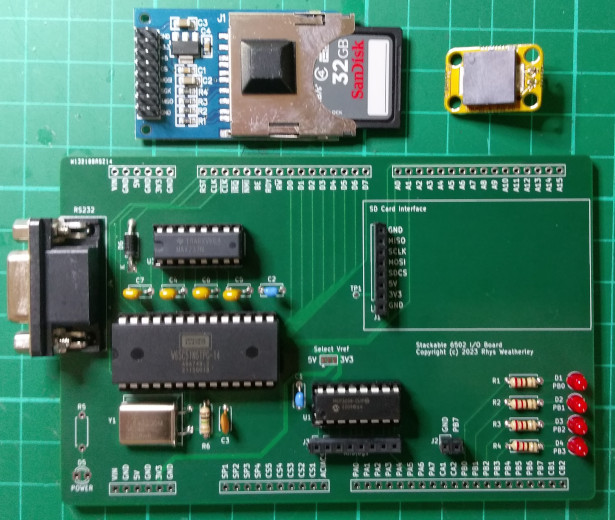
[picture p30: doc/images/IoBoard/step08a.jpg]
Extra modules


And here they are fitted to the board:

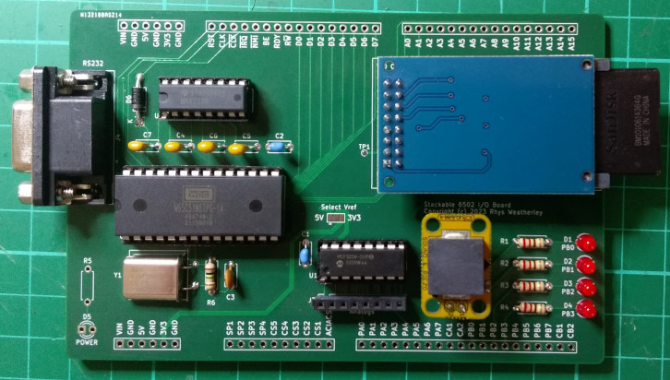
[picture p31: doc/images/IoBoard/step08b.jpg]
Extra modules fitted


I used a stick-on rubber foot to the SD card module to support it in place:

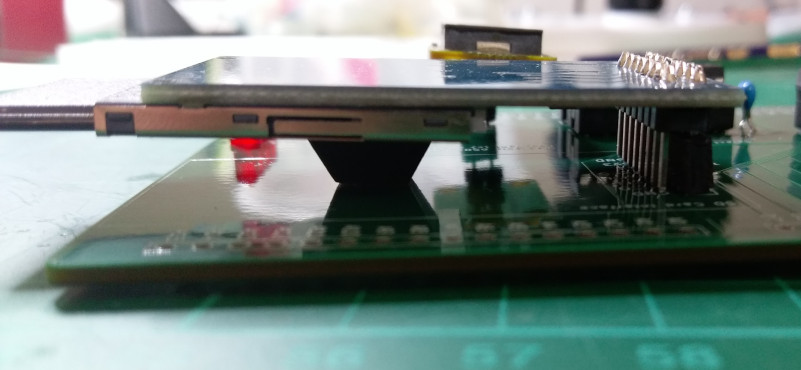
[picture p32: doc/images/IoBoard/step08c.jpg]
SD card module support


<a name="step-9"/>

## Step 9: Fit the stackable headers

Next fit the 2.54pm pin stackable headers, such as
[these ones from Adafruit](https://www.adafruit.com/product/3366).
Cut the six required headers to size:

* 2 x 6 pin headers for the voltage rails.
* 2 x 16 pin headers for address, data, and control lines.
* 1 x 10 pin header for the chip selects and spare pins.
* 1 x 20 pin header for the I/O ports on the 65C22 VIA.

When cutting the headers, score the cutting point with a hobby knife and
then snap the headers off with a pair of pliers.  The pin inserts tend to fall
out if you cut too close to the pins you want to keep.  I usually score the
cutting point close to the next pin.  You will lose one pin insert,
but you will have all the required pins in the snapped off portion.

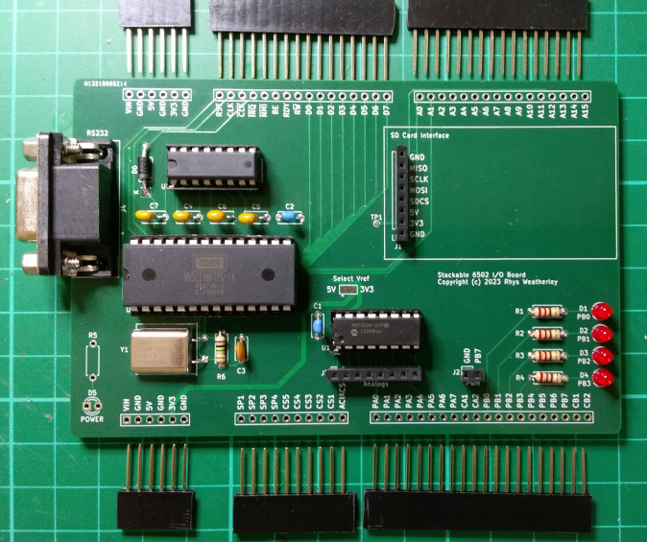
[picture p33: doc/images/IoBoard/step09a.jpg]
Stackable headers cut


Lining up the headers for hand soldering can seem like a challenge, but it is
quite easy if you plug the I/O board into headers on the already-soldered
base board.  This will line everything up:

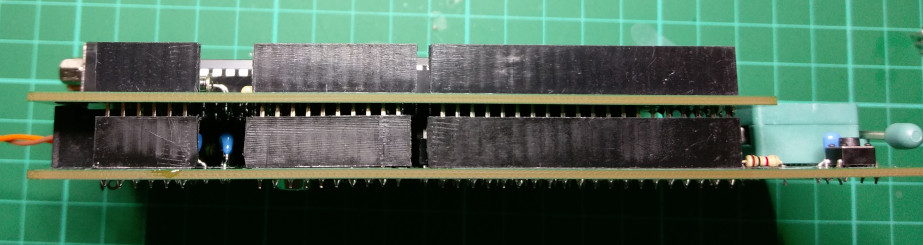
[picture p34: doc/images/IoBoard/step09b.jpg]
Stackable header fitting


Then quickly solder two pins on each header to tack them down.  Try not to
apply too much heat or you might melt the two boards together permanently!
A small glob of solder is enough even if the joint isn't perfect.

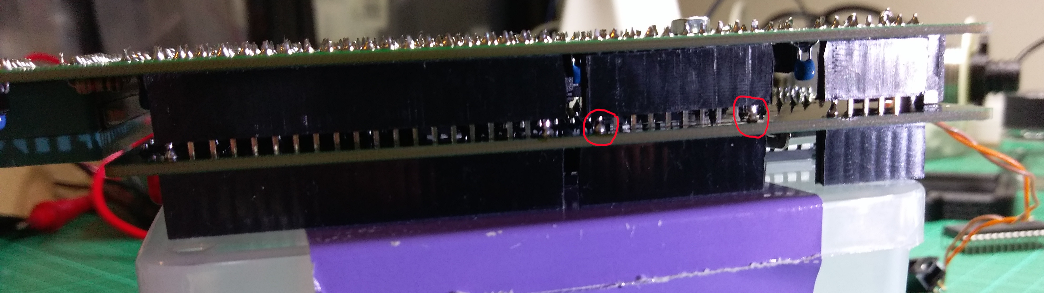
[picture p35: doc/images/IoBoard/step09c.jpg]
Stackable header soldering, part 1


Pull the two boards apart and solder the other pins.  You should also touch
up the solder joints on the pins you have already done.  Otherwise you
might have a dry joint.

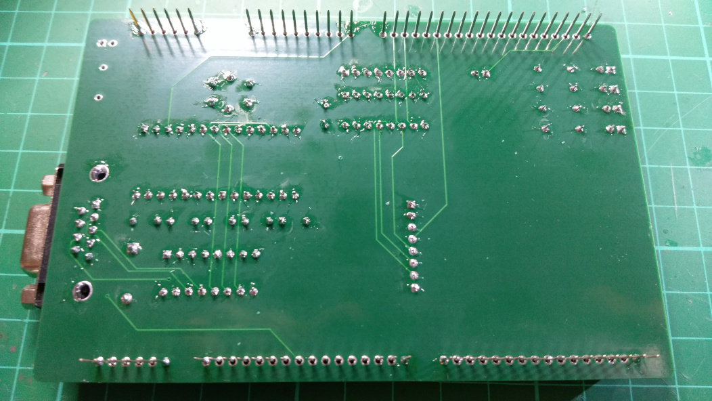
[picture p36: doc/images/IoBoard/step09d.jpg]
Stackable header soldering, part 2


And here is the finished product, connected to the base board:

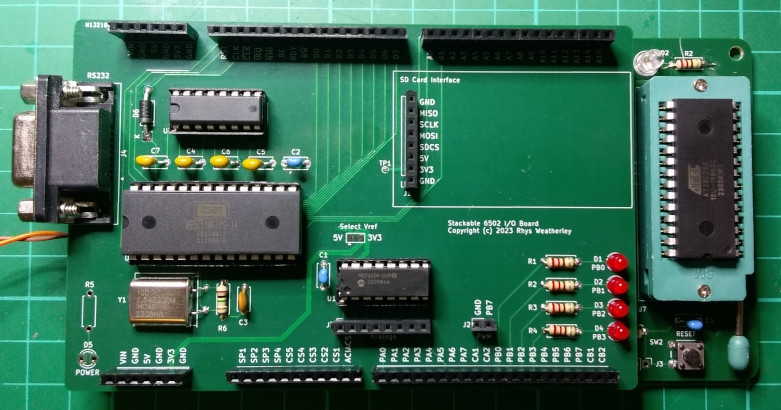
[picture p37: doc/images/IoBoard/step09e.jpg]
I/O board fully soldered


<a name="step-9"/>

## Step 10: Testing and Troubleshooting

Connect up a USB-to-serial converter to the RS232 port, and connect to
it with a terminal program configured for 19200 bps N-8-1.

Run the same selftest program as when
[Building the Base Board](Build-Base-Board.md#step-11) and troubleshoot
as described on that page.

If the 65C51 ACIA and the serial port are working, then you should
see text like the following in the terminal program:

    Self test started!
    Stack check: Running
    Stack check: Success
    Zero page check: Running
    Zero page check: Success
    RAM check: Filling memory
    RAM check: Verifying memory
    RAM check: Success
    BRK check: Running
    BRK check: Success
    Timer interrupt check: Running
    Timer interrupt check: Success
    PWM output check: Running
    PWM output check: Done
    ROM check: Running
    ROM check: Success
    All tests passed!

This tells you that serial transmit from the board is working.

Note: I sometimes have issues with my USB-to-serial converter where it
stops working on its own.  Unplugging the USB end from my desktop
computer and plugging it back in again can help.  So don't automatically
assume that the I/O board is not working.  It may be other equipment!

After you see "All tests passed!", you can type in characters and
see if they are echo'ed back to you:

    ...
    ROM check: Running
    ROM check: Success
    All tests passed!
    abcd
    878jdfkjdkfj
    It's working!

If the echo works, then serial receive is also working.  Congratulations!
You now have a working Stackable 6502 I/O Board!

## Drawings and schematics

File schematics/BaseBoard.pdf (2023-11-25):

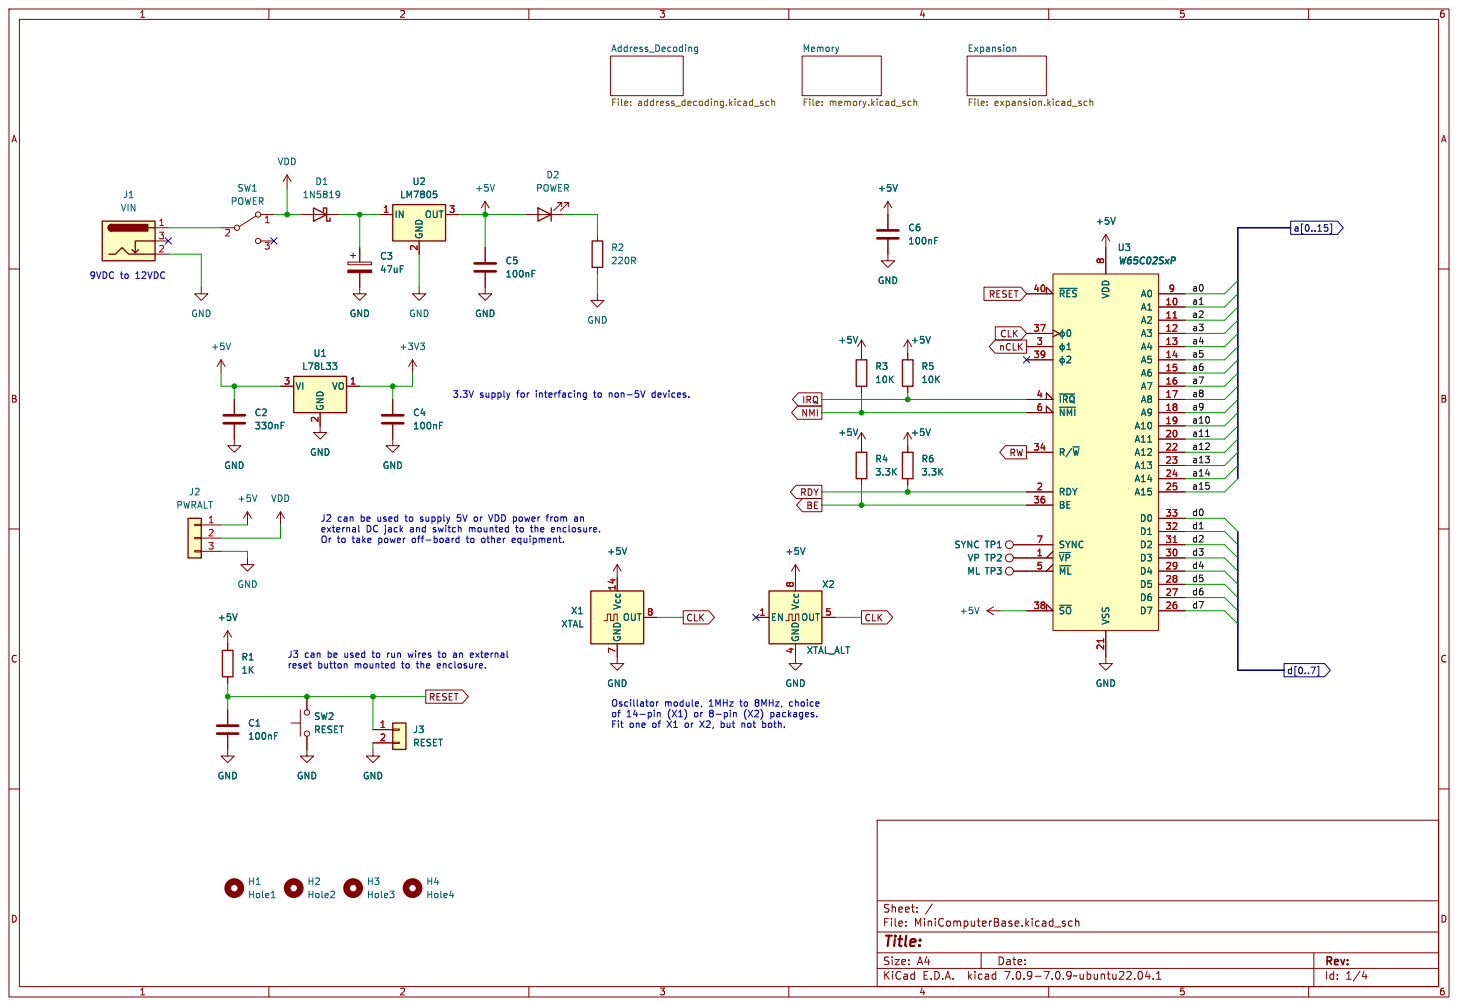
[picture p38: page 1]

7 OUT X1 8 XTAL SW2 RESET GND

Id: 1/4 Title: File: MiniComputerBase.kicad_sch Sheet: /

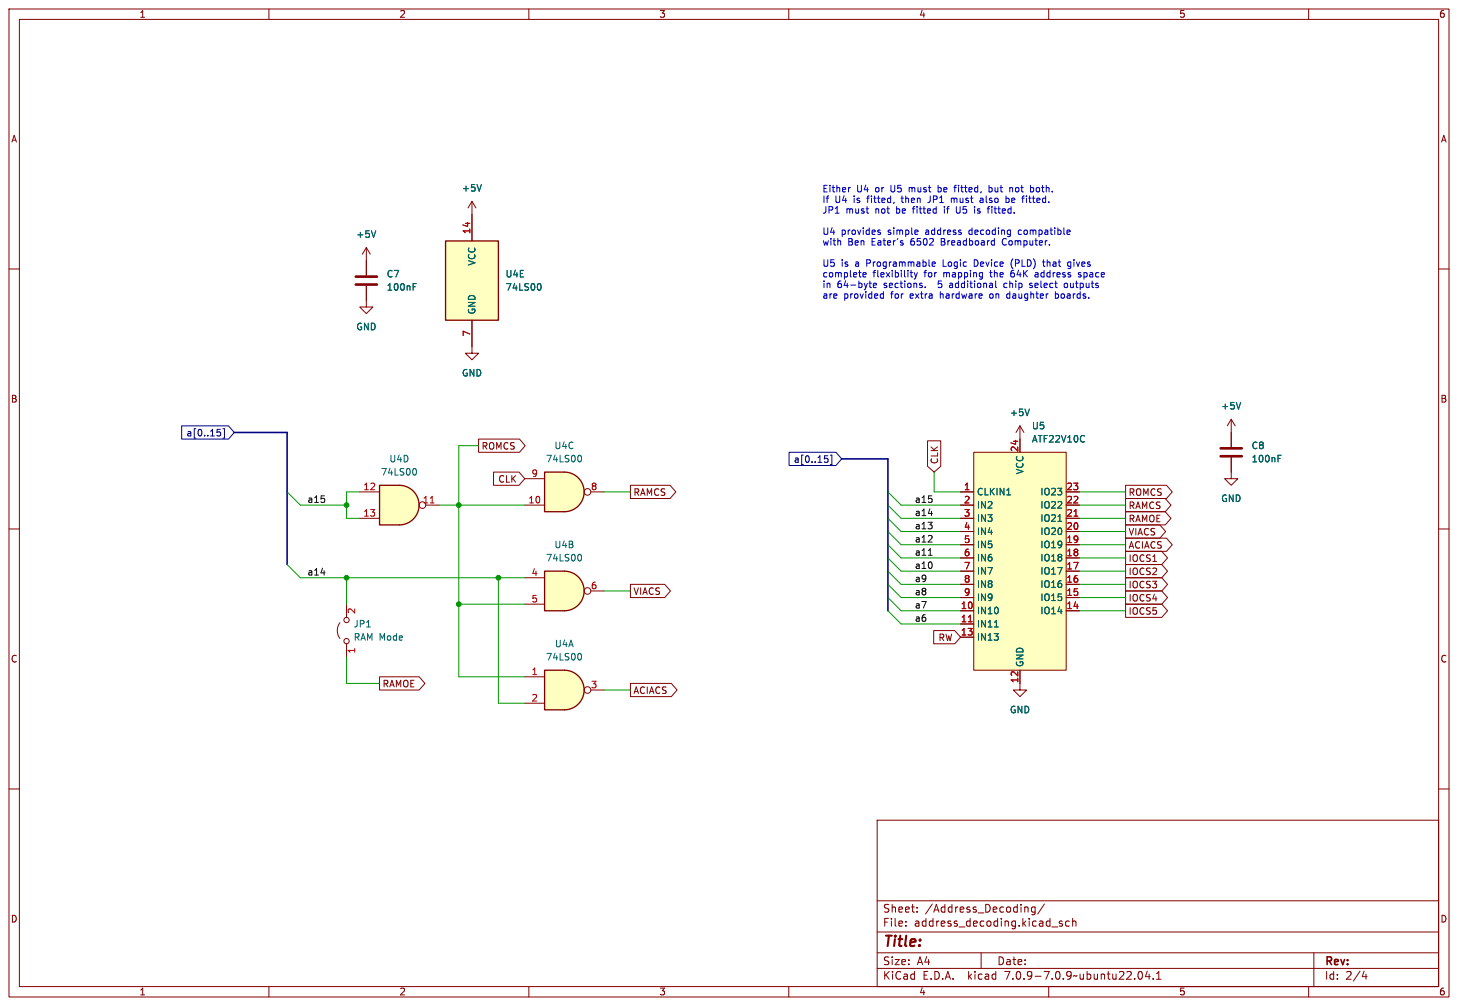
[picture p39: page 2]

Either U4 or U5 must be fitted, but not both.

Id: 2/4 Title: File: address_decoding.kicad_sch Sheet: /Address_Decoding/

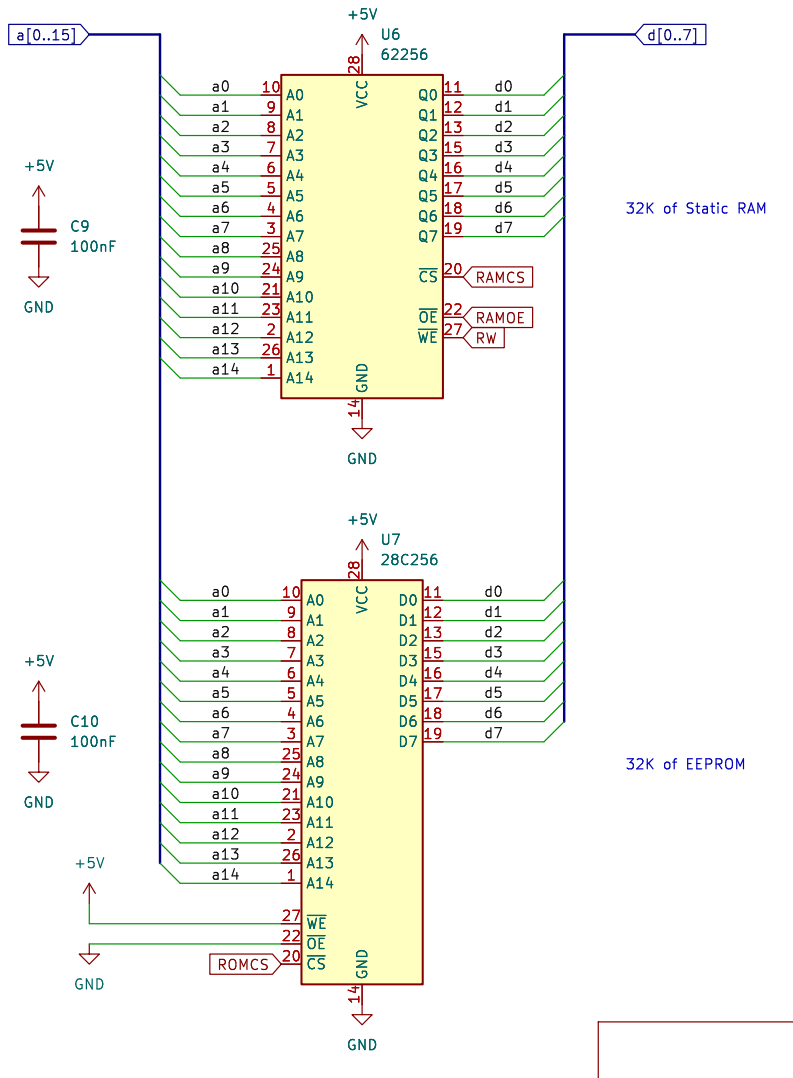
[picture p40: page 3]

Id: 3/4 Title: File: memory.kicad_sch Sheet: /Memory/ GND

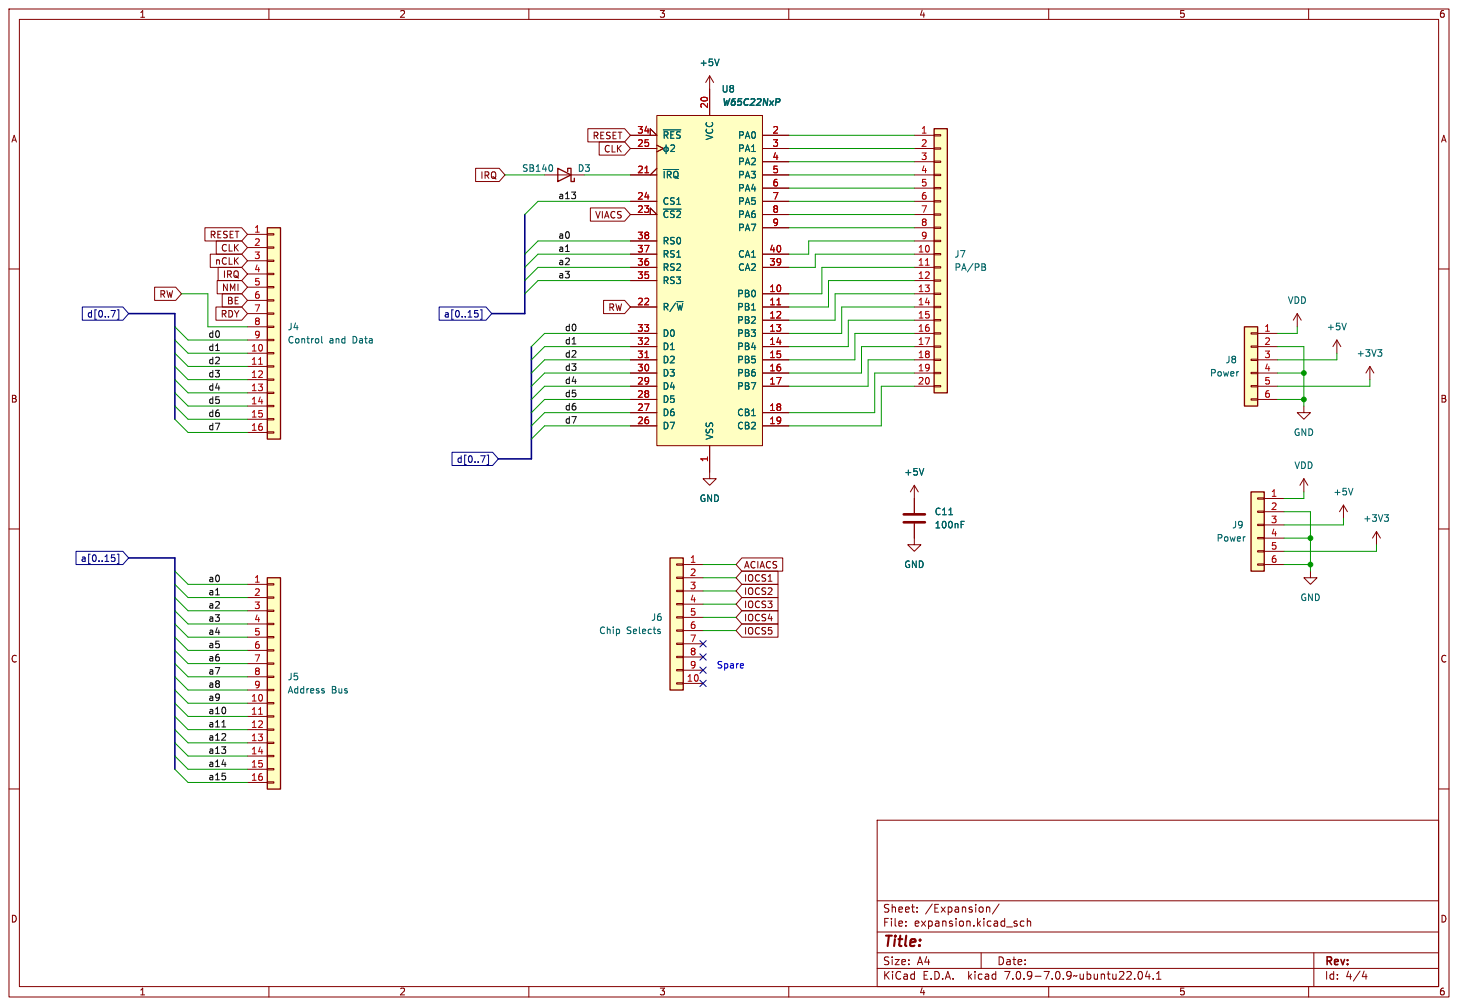
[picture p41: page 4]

BE CLK RESET NMI

Id: 4/4 Title: File: expansion.kicad_sch Sheet: /Expansion/

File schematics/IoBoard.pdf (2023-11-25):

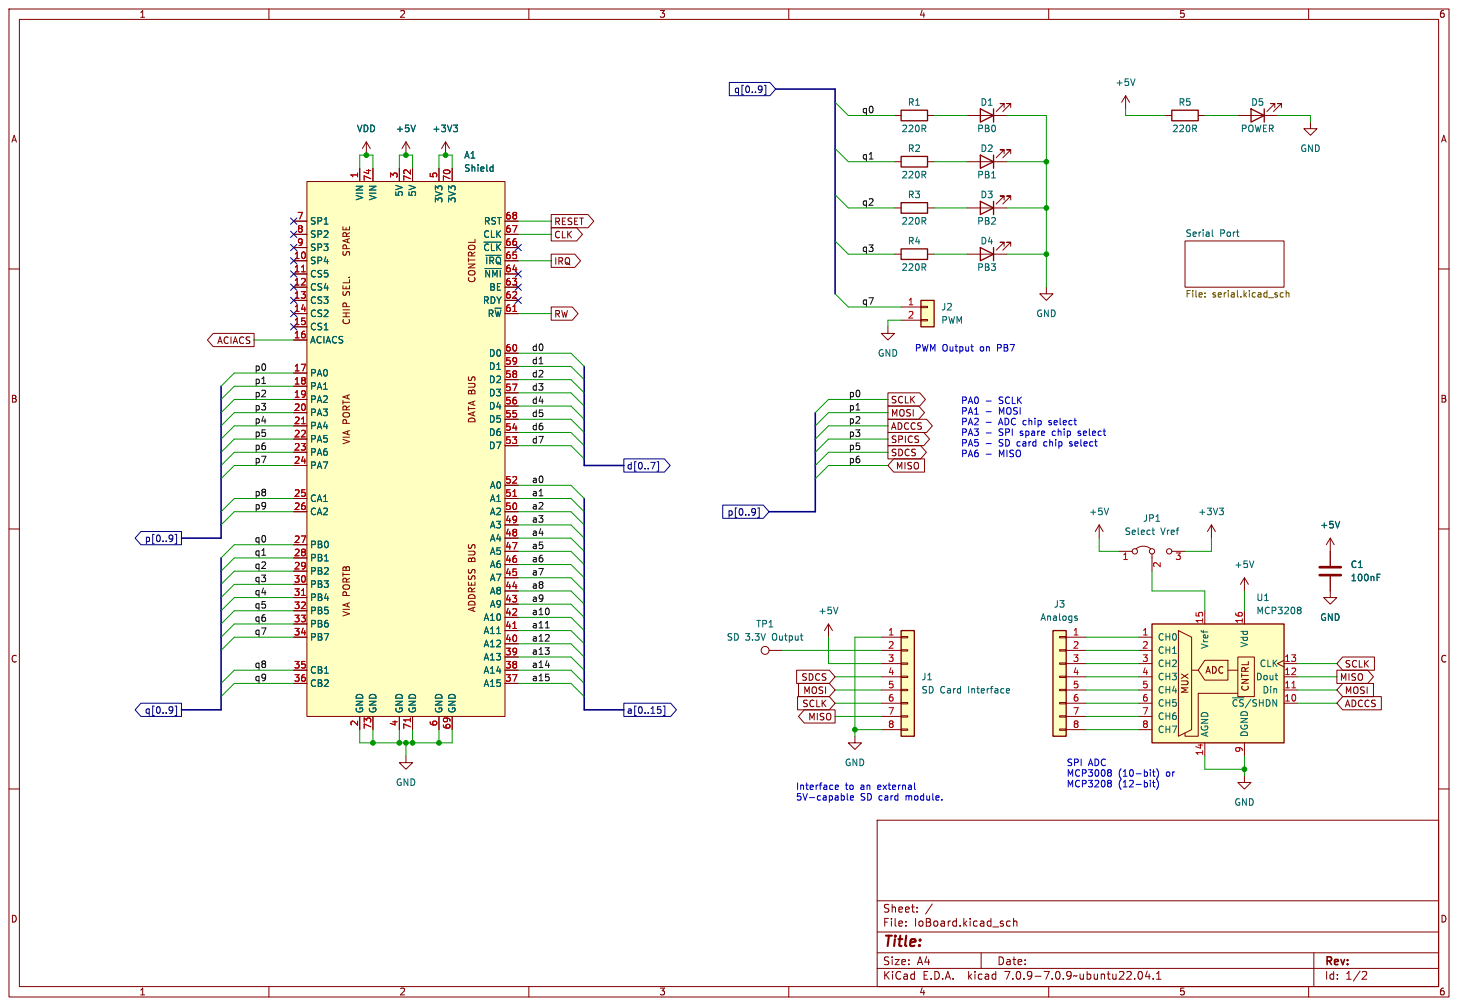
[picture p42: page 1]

ADCCS MOSI CLK RESET

PWM Output on PB7 PA0 - SCLK

PA1 - MOSI PA2 - ADC chip select PA3 - SPI spare chip select PA5 - SD card chip select PA6 - MISO

Id: 1/2 Title: File: IoBoard.kicad_sch Sheet: /

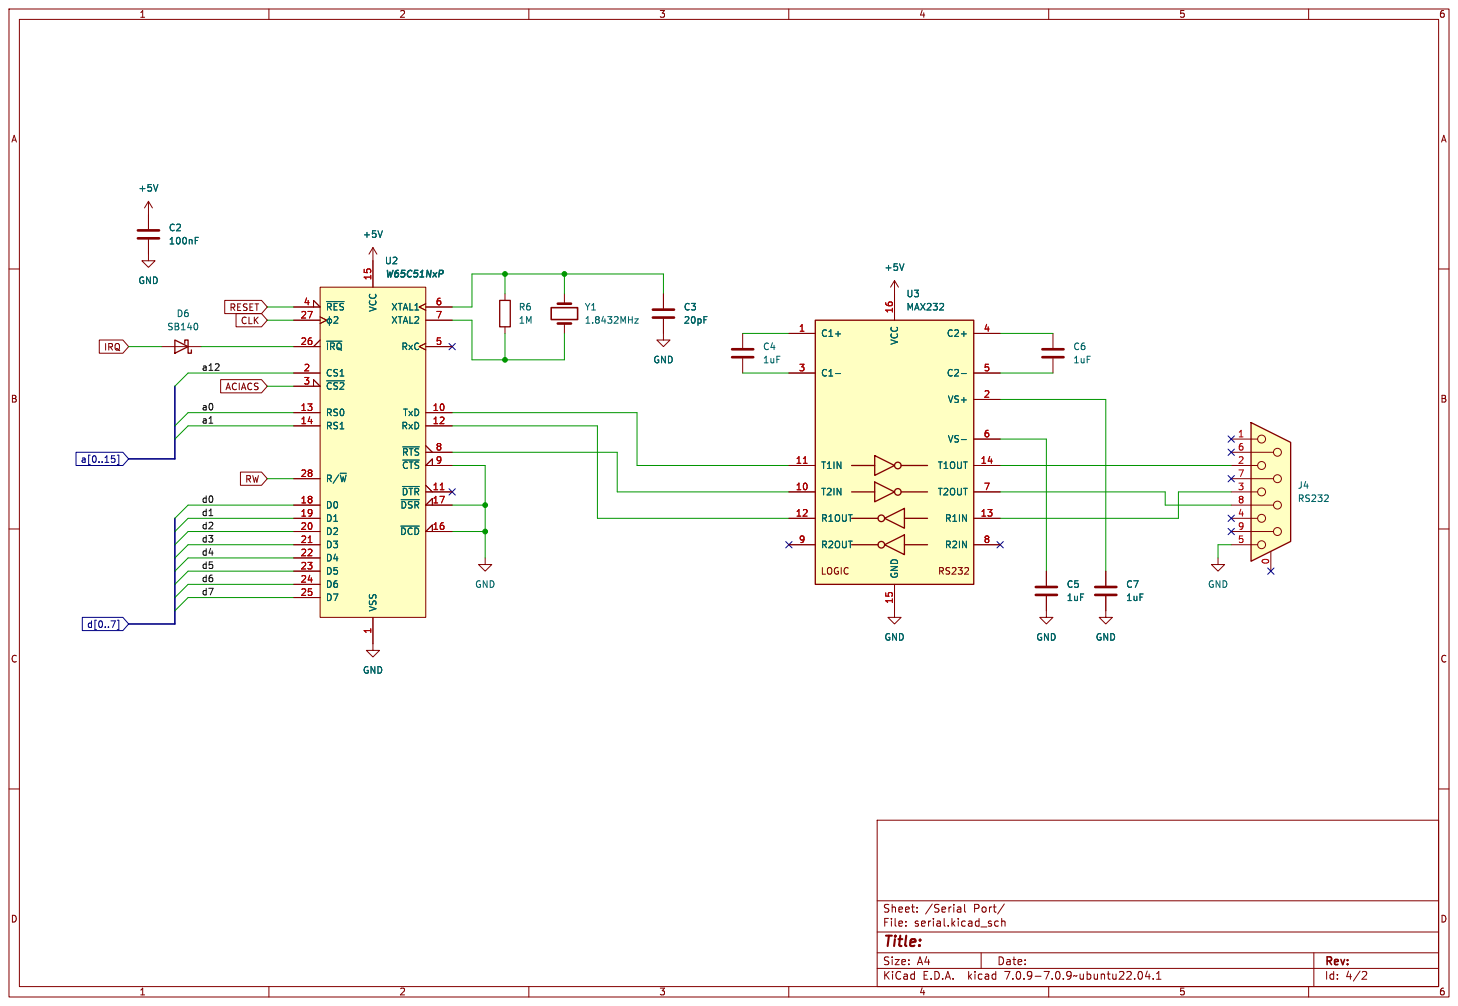
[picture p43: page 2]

1 TxD 10 ~{DTR}11 RxD 12 RS0 13 RS1 14 VCC 15

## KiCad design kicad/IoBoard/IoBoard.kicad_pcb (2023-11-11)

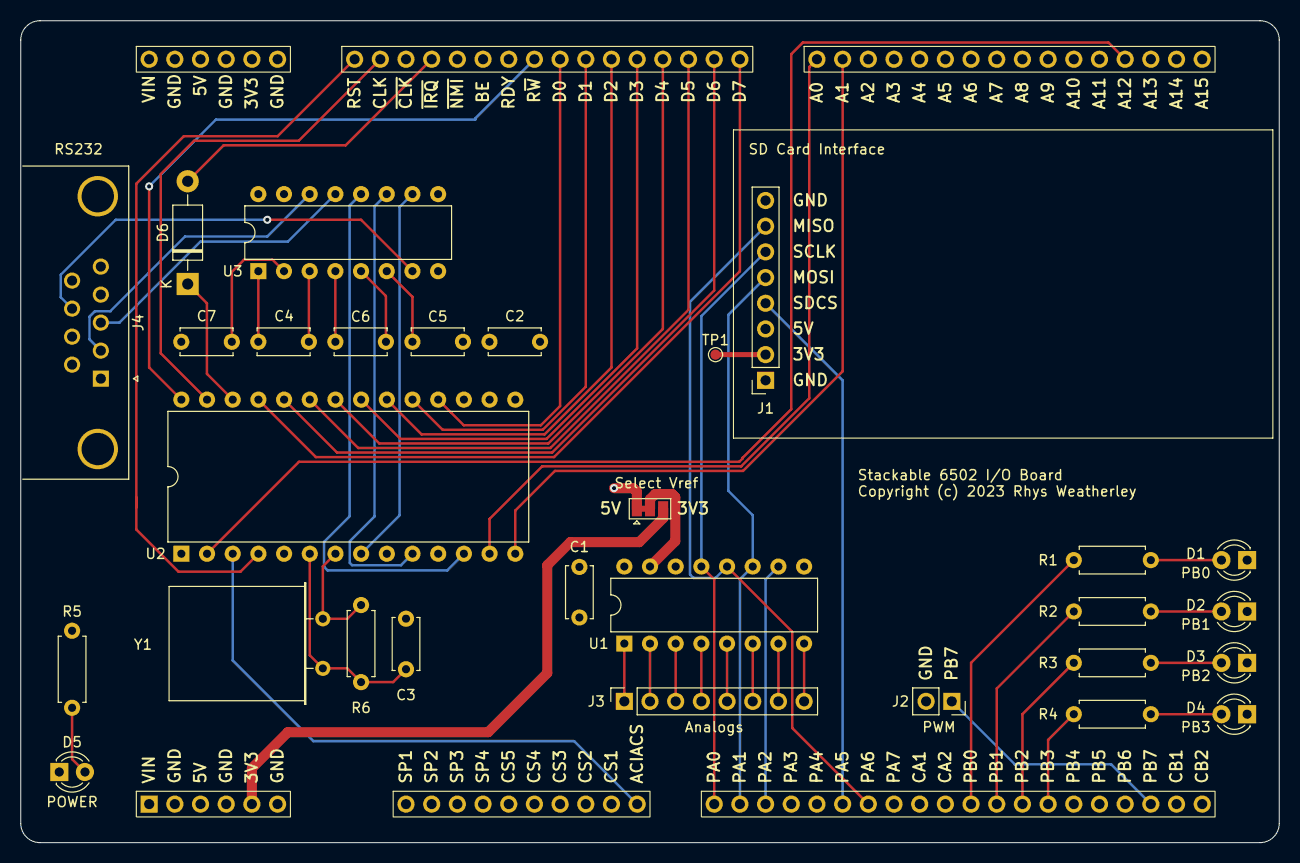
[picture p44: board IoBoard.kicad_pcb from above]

Board: 4 copper layers, 124.5 x 81.3 mm, 30 parts (0 on the bottom side), 60 nets.

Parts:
A1: Shield; Stackable6502Shield
C1, C2: 100nF; C_Disc_D5.0mm_W2.5mm_P5.00mm
C3: 20pF; C_Disc_D5.0mm_W2.5mm_P5.00mm
C4, C5, C6, C7: 1uF; C_Disc_D5.0mm_W2.5mm_P5.00mm
D1: PB0; LED_D3.0mm
D2: PB1; LED_D3.0mm
D3: PB2; LED_D3.0mm
D4: PB3; LED_D3.0mm
D5: POWER; LED_D3.0mm
D6: SB140; D_DO-41_SOD81_P10.16mm_Horizontal
J1: SD Card Interface; PinSocket_1x08_P2.54mm_Vertical
J2: PWM; PinSocket_1x02_P2.54mm_Vertical
J3: Analogs; PinSocket_1x08_P2.54mm_Vertical
J4: RS232; DSUB-9_Female_Horizontal_P2.77x2.84mm_EdgePinOffset4.94mm_H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
JP1: Select Vref; SolderJumper-3_P1.3mm_Bridged12_Pad1.0x1.5mm
R1, R2, R3, R4, R5: 1K; R_Axial_DIN0207_L6.3mm_D2.5mm_P7.62mm_Horizontal
R6: 1M; R_Axial_DIN0207_L6.3mm_D2.5mm_P7.62mm_Horizontal
TP1: SD 3.3V Output; TestPoint_Pad_D1.0mm
U1: MCP3208; DIP-16_W7.62mm
U2: W65C51NxP; DIP-28_W15.24mm
U3: MAX232; DIP-16_W7.62mm
Y1: 1.8432MHz; Crystal_HC49-U_Horizontal

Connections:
+3V3: A1.5 (3V3), A1.70 (3V3), JP1.3 (B)
+5V: A1.3 (5V), A1.72 (5V), C1.1, C2.1, J1.3, JP1.1 (A), R5.1, U1.16 (Vdd), U2.15 (VCC), U3.16 (VCC)
ACIACS: A1.16 (ACIACS), U2.3 (~CS2)
ADCCS: A1.19 (PA2), U1.10 (~CS/SHDN)
CLK: A1.67 (CLK), U2.27 (ϕ2)
GND: A1.2 (GND), A1.4 (GND), A1.6 (GND), A1.69 (GND), A1.71 (GND), A1.73 (GND), C1.2, C2.2, C3.2, C5.2, C7.2, D1.1 (K), D2.1 (K), D3.1 (K), D4.1 (K), D5.1 (K), J1.1, J1.8, J2.2, J4.5, U1.9 (DGND), U1.14 (AGND), U2.1 (VSS), U2.9 (~CTS), U2.16 (~DCD), U2.17 (~DSR), U3.15 (GND)
IRQ: A1.65 (~IRQ), D6.2 (A)
MISO: A1.23 (PA6), J1.7, U1.12 (Dout)
MOSI: A1.18 (PA1), J1.5, U1.11 (Din)
unnamed: D1.2 (A), R1.2
unnamed: D2.2 (A), R2.2
unnamed: D3.2 (A), R3.2
unnamed: D4.2 (A), R4.2
unnamed: D5.2 (A), R5.2
unnamed: D6.1 (K), U2.26 (~IRQ)
unnamed: J1.2, TP1.1
unnamed: J3.1, U1.1 (CH0)
unnamed: J3.2, U1.2 (CH1)
unnamed: J3.3, U1.3 (CH2)
unnamed: J3.4, U1.4 (CH3)
unnamed: J3.5, U1.5 (CH4)
unnamed: J3.6, U1.6 (CH5)
unnamed: J3.7, U1.7 (CH6)
unnamed: J3.8, U1.8 (CH7)
unnamed: JP1.2 (C), U1.15 (Vref)
unnamed: U2.12 (RxD), U3.12 (R1OUT)
unnamed: U2.10 (TxD), U3.11 (T1IN)
unnamed: C3.1, R6.1, U2.6 (XTAL1), Y1.2
unnamed: R6.2, U2.7 (XTAL2), Y1.1
unnamed: U2.8 (~RTS), U3.10 (T2IN)
unnamed: C4.1, U3.1 (C1+)
unnamed: C4.2, U3.3 (C1-)
unnamed: C6.1, U3.4 (C2+)
unnamed: C6.2, U3.5 (C2-)
unnamed: J4.3, U3.13 (R1IN)
unnamed: J4.2, U3.14 (T1OUT)
unnamed: J4.8, U3.7 (T2OUT)
unnamed: C7.1, U3.2 (VS+)
unnamed: C5.1, U3.6 (VS-)
RESET: A1.68 (RST), U2.4 (~RES)
RW: A1.61 (R~W), U2.28 (R/~W)
SCLK: A1.17 (PA0), J1.6, U1.13 (CLK)
SDCS: A1.22 (PA5), J1.4
VDD: A1.1 (VIN), A1.74 (VIN)
a0: A1.52 (A0), U2.13 (RS0)
a1: A1.51 (A1), U2.14 (RS1)
a12: A1.40 (A12), U2.2 (CS1)
d0: A1.60 (D0), U2.18 (D0)
d1: A1.59 (D1), U2.19 (D1)
d2: A1.58 (D2), U2.20 (D2)
d3: A1.57 (D3), U2.21 (D3)
d4: A1.56 (D4), U2.22 (D4)
d5: A1.55 (D5), U2.23 (D5)
d6: A1.54 (D6), U2.24 (D6)
d7: A1.53 (D7), U2.25 (D7)
q0: A1.27 (PB0), R1.1
q1: A1.28 (PB1), R2.1
q2: A1.29 (PB2), R3.1
q3: A1.30 (PB3), R4.1
q7: A1.34 (PB7), J2.1

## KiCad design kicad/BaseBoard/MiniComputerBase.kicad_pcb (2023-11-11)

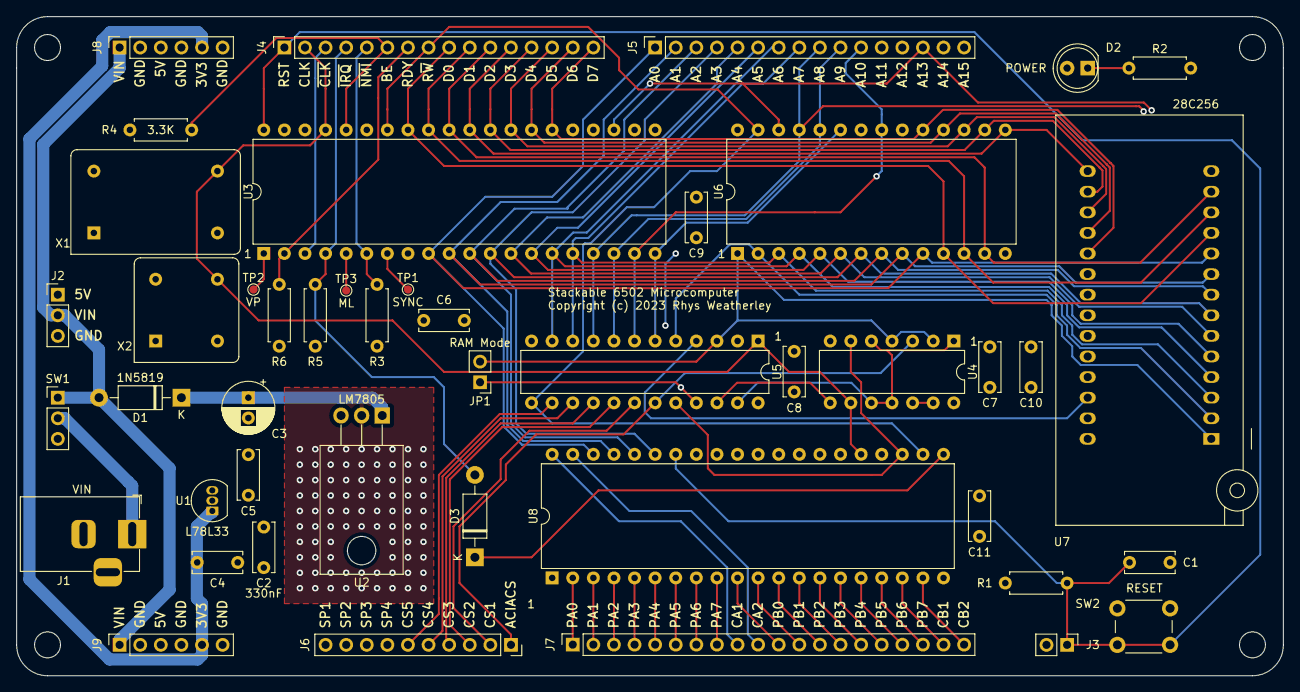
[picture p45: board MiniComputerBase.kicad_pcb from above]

Board: 4 copper layers, 156.2 x 81.3 mm, 49 parts (0 on the bottom side), 73 nets.

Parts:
C1, C4, C5, C6, C7, C8, C9, C10, C11: 100nF; C_Disc_D6.0mm_W2.5mm_P5.00mm
C2: 330nF; C_Disc_D6.0mm_W2.5mm_P5.00mm
C3: 47uF; CP_Radial_D6.3mm_P2.50mm
D1: 1N5819; D_DO-41_SOD81_P10.16mm_Horizontal
D2: POWER; LED_D5.0mm
D3: SB140; D_DO-41_SOD81_P10.16mm_Horizontal
H1: Hole1; MountingHole_3.2mm_M3
H2: Hole2; MountingHole_3.2mm_M3
H3: Hole3; MountingHole_3.2mm_M3
H4: Hole4; MountingHole_3.2mm_M3
J1: VIN; BarrelJack_Horizontal
J2: PWRALT; PinHeader_1x03_P2.54mm_Vertical
J3: RESET; PinHeader_1x02_P2.54mm_Vertical
J4: Control and Data; PinSocket_1x16_P2.54mm_Vertical
J5: Address Bus; PinSocket_1x16_P2.54mm_Vertical
J6: Chip Selects; PinSocket_1x10_P2.54mm_Vertical
J7: PA/PB; PinSocket_1x20_P2.54mm_Vertical
J8, J9: Power; PinSocket_1x06_P2.54mm_Vertical
JP1: RAM Mode; PinHeader_1x02_P2.54mm_Vertical
R1: 1K; R_Axial_DIN0207_L6.3mm_D2.5mm_P7.62mm_Horizontal
R2: 220R; R_Axial_DIN0207_L6.3mm_D2.5mm_P7.62mm_Horizontal
R3, R5: 10K; R_Axial_DIN0207_L6.3mm_D2.5mm_P7.62mm_Horizontal
R4, R6: 3.3K; R_Axial_DIN0207_L6.3mm_D2.5mm_P7.62mm_Horizontal
SW1: POWER; PinHeader_1x03_P2.54mm_Vertical
SW2: RESET; SW_PUSH_6mm_H5mm
TP1: SYNC; TestPoint_Pad_D1.0mm
TP2: VP; TestPoint_Pad_D1.0mm
TP3: ML; TestPoint_Pad_D1.0mm
U1: L78L33; TO-92_Inline
U2: LM7805; TO-220-3_Horizontal_TabDown
U3: W65C02SxP; DIP-40_W15.24mm
U4: 74LS00; DIP-14_W7.62mm
U5: ATF22V10C; DIP-24_W7.62mm
U6: 62256; DIP-28_W15.24mm
U7: 28C256; DIP_Socket-28_W11.9_W12.7_W15.24_W17.78_W18.5_3M_228-1277-0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
U8: W65C22NxP; DIP-40_W15.24mm
X1: XTAL; Oscillator_DIP-14
X2: XTAL_ALT; Oscillator_DIP-8

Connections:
+3V3: C4.1, J8.5, J9.5, U1.1 (VO)
+5V: C2.1, C5.1, C6.1, C7.1, C8.1, C9.1, C10.1, C11.1, D2.2 (A), J2.1, J8.3, J9.3, R1.1, R3.1, R4.1, R5.1, R6.1, U1.3 (VI), U2.3 (OUT), U3.8 (VDD), U3.38 (~SO), U4.14 (VCC), U5.24 (VCC), U6.28 (VCC), U7.27 (~WE), U7.28 (VCC), U8.20 (VCC), X1.14 (Vcc), X2.8 (Vcc)
ACIACS: J6.1, U4.3, U5.19 (IO19)
BE: J4.6, R4.2, U3.36 (BE)
CLK: J4.2, U3.37 (ϕ0), U4.9, U5.1 (CLKIN1), U8.25 (ϕ2), X1.8 (OUT), X2.5 (OUT)
GND: C1.2, C2.2, C3.2, C4.2, C5.2, C6.2, C7.2, C8.2, C9.2, C10.2, C11.2, J1.2, J2.3, J3.2, J8.2, J8.4, J8.6, J9.2, J9.4, J9.6, R2.2, SW2.1, U1.2 (GND), U2.2 (GND), U3.21 (VSS), U4.7 (GND), U5.12 (GND), U6.14 (GND), U7.14 (GND), U7.22 (~OE), U8.1 (VSS), X1.7 (GND), X2.4 (GND)
IOCS1: J6.2, U5.18 (IO18)
IOCS2: J6.3, U5.17 (IO17)
IOCS3: J6.4, U5.16 (IO16)
IOCS4: J6.5, U5.15 (IO15)
IOCS5: J6.6, U5.14 (IO14)
IRQ: D3.2 (A), J4.4, R5.2, U3.4 (~IRQ)
NMI: J4.5, R3.2, U3.6 (~NMI)
unnamed: C3.1, D1.1 (K), U2.1 (IN)
unnamed: D2.1 (K), R2.1
unnamed: D3.1 (K), U8.21 (~IRQ)
unnamed: J7.1, U8.2 (PA0)
unnamed: J7.2, U8.3 (PA1)
unnamed: J7.3, U8.4 (PA2)
unnamed: J7.4, U8.5 (PA3)
unnamed: J7.5, U8.6 (PA4)
unnamed: J7.6, U8.7 (PA5)
unnamed: J7.7, U8.8 (PA6)
unnamed: J7.8, U8.9 (PA7)
unnamed: J7.9, U8.40 (CA1)
unnamed: J7.10, U8.39 (CA2)
unnamed: J7.11, U8.10 (PB0)
unnamed: J7.12, U8.11 (PB1)
unnamed: J7.13, U8.12 (PB2)
unnamed: J7.14, U8.13 (PB3)
unnamed: J7.15, U8.14 (PB4)
unnamed: J7.16, U8.15 (PB5)
unnamed: J7.17, U8.16 (PB6)
unnamed: J7.18, U8.17 (PB7)
unnamed: J7.19, U8.18 (CB1)
unnamed: J7.20, U8.19 (CB2)
unnamed: J1.1, SW1.2 (B)
unnamed: TP1.1, U3.7 (SYNC)
unnamed: TP3.1, U3.5 (~ML)
unnamed: TP2.1, U3.1 (~VP)
RAMCS: U4.8, U5.22 (IO22), U6.20 (~CS)
RAMOE: JP1.1 (A), U5.21 (IO21), U6.22 (~OE)
RDY: J4.7, R6.2, U3.2 (RDY)
RESET: C1.1, J3.1, J4.1, R1.2, SW2.2, U3.40 (~RES), U8.34 (~RES)
ROMCS: U4.1, U4.5, U4.10, U4.11, U5.23 (IO23), U7.20 (~CS)
RW: J4.8, U3.34 (R/~W), U5.13 (IN13), U6.27 (~WE), U8.22 (R/~W)
VDD: D1.2 (A), J2.2, J8.1, J9.1, SW1.1 (A)
VIACS: U4.6, U5.20 (IO20), U8.23 (~CS2)
a0: J5.1, U3.9 (A0), U6.10 (A0), U7.10 (A0), U8.38 (RS0)
a1: J5.2, U3.10 (A1), U6.9 (A1), U7.9 (A1), U8.37 (RS1)
a2: J5.3, U3.11 (A2), U6.8 (A2), U7.8 (A2), U8.36 (RS2)
a3: J5.4, U3.12 (A3), U6.7 (A3), U7.7 (A3), U8.35 (RS3)
a4: J5.5, U3.13 (A4), U6.6 (A4), U7.6 (A4)
a5: J5.6, U3.14 (A5), U6.5 (A5), U7.5 (A5)
a6: J5.7, U3.15 (A6), U5.11 (IN11), U6.4 (A6), U7.4 (A6)
a7: J5.8, U3.16 (A7), U5.10 (IN10), U6.3 (A7), U7.3 (A7)
a8: J5.9, U3.17 (A8), U5.9 (IN9), U6.25 (A8), U7.25 (A8)
a9: J5.10, U3.18 (A9), U5.8 (IN8), U6.24 (A9), U7.24 (A9)
a10: J5.11, U3.19 (A10), U5.7 (IN7), U6.21 (A10), U7.21 (A10)
a11: J5.12, U3.20 (A11), U5.6 (IN6), U6.23 (A11), U7.23 (A11)
a12: J5.13, U3.22 (A12), U5.5 (IN5), U6.2 (A12), U7.2 (A12)
a13: J5.14, U3.23 (A13), U5.4 (IN4), U6.26 (A13), U7.26 (A13), U8.24 (CS1)
a14: J5.15, JP1.2 (B), U3.24 (A14), U4.2, U4.4, U5.3 (IN3), U6.1 (A14), U7.1 (A14)
a15: J5.16, U3.25 (A15), U4.12, U4.13, U5.2 (IN2)
d0: J4.9, U3.33 (D0), U6.11 (Q0), U7.11 (D0), U8.33 (D0)
d1: J4.10, U3.32 (D1), U6.12 (Q1), U7.12 (D1), U8.32 (D1)
d2: J4.11, U3.31 (D2), U6.13 (Q2), U7.13 (D2), U8.31 (D2)
d3: J4.12, U3.30 (D3), U6.15 (Q3), U7.15 (D3), U8.30 (D3)
d4: J4.13, U3.29 (D4), U6.16 (Q4), U7.16 (D4), U8.29 (D4)
d5: J4.14, U3.28 (D5), U6.17 (Q5), U7.17 (D5), U8.28 (D5)
d6: J4.15, U3.27 (D6), U6.18 (Q6), U7.18 (D6), U8.27 (D6)
d7: J4.16, U3.26 (D7), U6.19 (Q7), U7.19 (D7), U8.26 (D7)
nCLK: J4.3, U3.3 (ϕ1)

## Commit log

2023-10-26 Base board schematic and layout
    [MiniComputerBase.kicad_pcb, MiniComputerBase.kicad_sch, address_decoding.kicad_sch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]
2023-11-11 I/O board schematic and layout
    [IoBoard.kicad_pcb, IoBoard.kicad_sch, MiniComputerBase.kicad_pcb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]
2023-11-11 Gerber files
    [IoBoard-B_Cu.gbl, IoBoard-B_Mask.gbs, IoBoard-B_Paste.gbp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]
2023-11-25 Component updates after first build
    [IoBoard.kicad_sch, MiniComputerBase.kicad_sch]
2023-11-25 Build instructions for the base board
2023-11-25 Add license and 3D rendering of base board
2023-11-26 Build instructions for the I/O board
2023-11-28 Power-on self test ROM for the device
2023-12-01 Glory shots of the finished boards
2023-12-01 Add links to shared PCBway project pages
2023-12-04 Add links to PCBway on the Parts.md page

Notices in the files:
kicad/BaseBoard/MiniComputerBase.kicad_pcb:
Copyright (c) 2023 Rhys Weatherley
